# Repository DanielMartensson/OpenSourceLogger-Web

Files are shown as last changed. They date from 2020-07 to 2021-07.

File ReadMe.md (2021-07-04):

# OpenSourceLogger

This software creates a web application with Spring Boot and with this web application you can control and measure analog inputs and outputs and 
store them into a MySQL database.

# Features

* 4 Analog inputs of 12-bit
* 2 Analog inputs of 16-bit
* 3 Analog inputs of 16-bit differential
* 9 PWM control outputs
* 6 Digital inputs
* 3 Analog outputs of 12-bit
* Circuit protection from high voltage
* Spring Security Login
* MySQL database
* USB Camera view (Does not work with Raspberry Pi)
* Plotting functionality
* SMTP alarm functionality
* CSV generation of measurements
* Connect with RX and TX from Raspberry Pi pins
* Save unsaved database measurement for later if database might be slow for a moment
* Close down PWM and analog outputs when stop logging or alarm goes of

With this user view, you can control PWM, DAC, read ADC and logging digital inputs online over the web.
Set an alarm and calibration of a special sensor you want to use. Store all data inside the database. 
Then later you can bring the measurement back to a plot. Notice that you can close down the web browser while you logging.
It will continue to sample in a separate thread. 

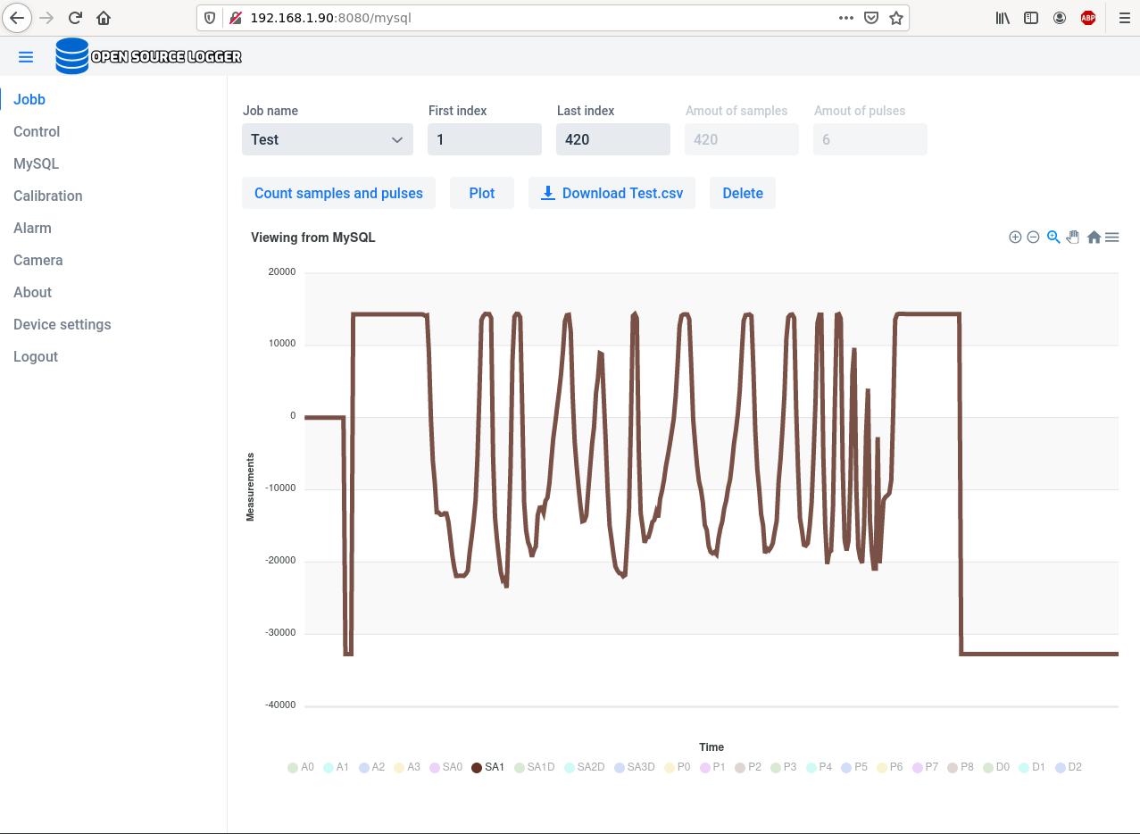
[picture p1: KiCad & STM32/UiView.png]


This is made in KiCad. I have drag all the tracks on the board by my self. No auto-routing here.

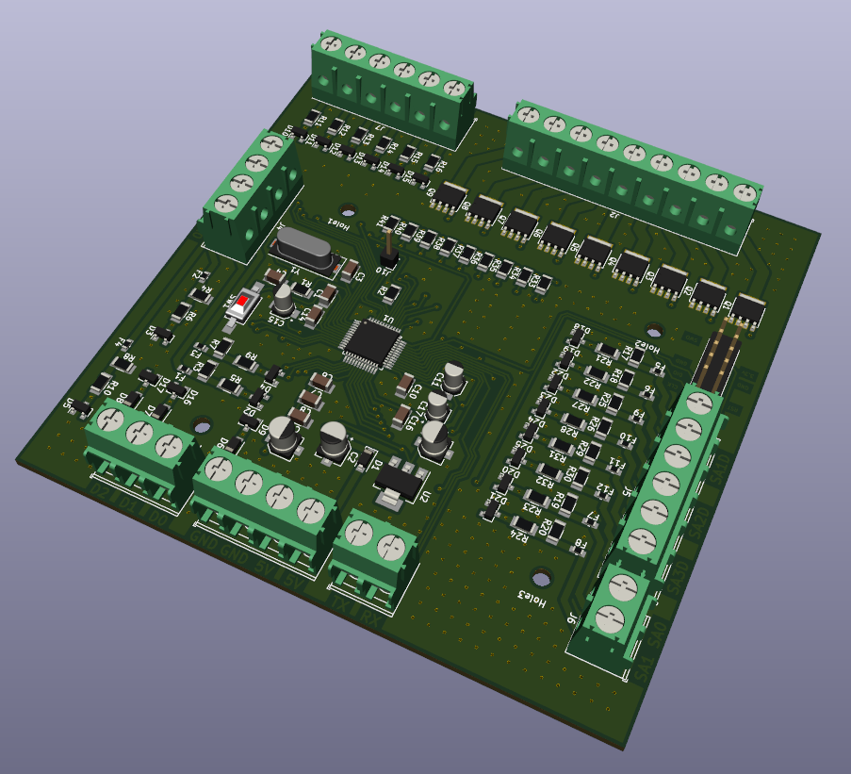
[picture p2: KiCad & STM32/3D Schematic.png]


I have solder all components by my self.

a

I have solder this microcontroller by hand. 

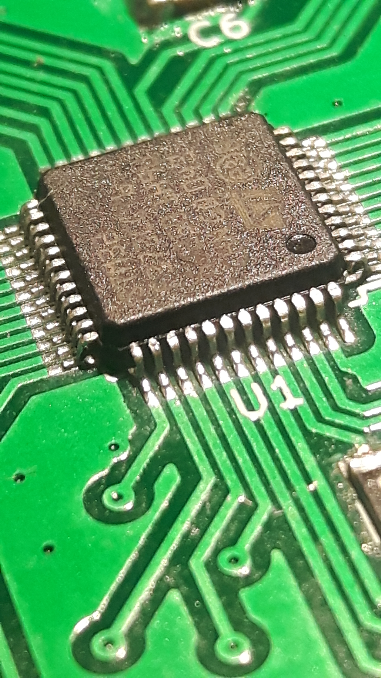
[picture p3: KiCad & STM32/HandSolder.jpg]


Applied inside a metallic box. Here I'm using Raspberry Pi to communicate with the board.
You can use a regular computer as well, as long you have a USB to serial converter, e.g `USB/UART converter FTDI FT232` where you connect `RXD -> TX` and `TXD -> RX` on the board.

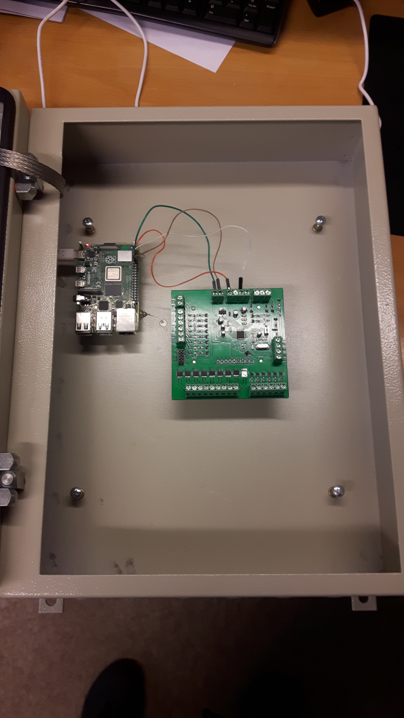
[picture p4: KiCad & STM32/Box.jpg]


# How to install - Ubuntu user

1. Install Java 11, Maven, NodeJS

Java 11
```
sudo apt-get install openjdk-11-jdk
```

Maven
```
sudo apt-get install maven
```

NodeJS
```
curl -sL https://deb.nodesource.com/setup_lts.x | sudo -E bash -
sudo apt-get install -y nodejs
```

2. Begin first to install MySQL Community Server

```
sudo apt-get install mysql-server
```

3. Then create a user e.g `myUser` with the password e.g `myPassword`

Login and enter your `sudo` password or mysql `root` password
```
sudo mysql -u root -p
```

Create user with the host `%` <-- That's important if you want to access your server from other computers.
```
CREATE USER 'myUser'@'%' IDENTIFIED BY 'myPassword';
```

Set the privileges to that user
```
GRANT ALL PRIVILEGES ON *.* TO 'myUser'@'%';
```

4. Change your MySQL server so you listening to your LAN address

Open this file
```
/etc/mysql/mysql.conf.d/mysqld.conf
```

And change this
```
bind-address            = 127.0.0.1
```

To your LAN address where the server is installed on e.g
```
bind-address            = 192.168.1.34
```

Then restart your MySQL server
```
sudo /etc/init.d/mysql restart
```

If you don't know your LAN address, you can type in this command in linux `ifconfig` in the terminal

5. Download `OpenSourceLogger`

Download the `OpenSourceLogger` and change the `application.properties` in the `/src/main/resources` folder.
Here you can set the configuration for your database IP address, user and password. Here set the address of your `Outlook` account.
The `service.MailService.from` must be the same as `configuration.MailConfiguration.username`.

```
# Database
spring.jpa.show-sql=true
spring.jpa.hibernate.ddl-auto=update
spring.jpa.properties.hibernate.dialect=org.hibernate.dialect.MySQL5Dialect
spring.datasource.url=jdbc:mysql://yourIPAddressOfTheServerWhereMySQLIsInstalled:3306/OpenSourceLogger?createDatabaseIfNotExist=true&serverTimezone=CET
spring.datasource.username=myUser
spring.datasource.password=myPassword

# Mail - Transmitter
configuration.MailConfiguration.host=smtp.office365.com
configuration.MailConfiguration.port=587
configuration.MailConfiguration.username=yourOutlookAccount@outlook.com
configuration.MailConfiguration.password=yourOutlookPassword

# Mail - Receiver
service.MailService.subject=Alarm Message Subject Title
service.MailService.from=yourOutlookAccount@outlook.com

# Login
spring.security.user.name=myUser
spring.security.user.password=myPassword
```

6. Pack this project and run

First stand inside of the folder `OpenSourceLogger` and write inside your terminal
```
mvn package -Pproduction
```

7. Starting the application

Now a JAR file is created inside the `OpenSourceLogger/target` folder. 

You can start `opensourcelogger-1.0-SNAPSHOT.jar`. First plugin your Serial UART into your USB port first, then write. 

```
sudo java -jar opensourcelogger-1.0-SNAPSHOT.jar
```

Once the application is started. You can then enter the web application e.g.

```
http://192.168.1.35:8080
```
Notice that there is no `https`, only `http`.

# Deploy onto Raspberry Pi

Notice that camera won't work on Raspberry Pi due to the latest library from [Sarox](https://github.com/sarxos/webcam-capture) cannot support Raspberry Pi 4B. But you can 
do everything else. If you want to work with this camera stuff inside `OpenSourceLogger`, please go to `CameraThread.java` class and begin to explore how to solve that problem.

Anyway! Once you got `opensourcelogger-1.0-SNAPSHOT.jar` ready, you can send it to your Raspberry Pi.

```
sudo scp opensourcelogger-1.0-SNAPSHOT.jar pi@RaspberryPiIPAddress:/The/Place/You/Want/The/Jar/File/To/Be/Saved
```

Example:

```
sudo scp opensourcelogger-1.0-SNAPSHOT.jar pi@192.168.1.35:/home/pi
```

Then open `rc.local`

```
sudo nano /etc/rc.local
```

And place these line above `exit 0`

```
cd /The/Path/To/Where/The/Jar/File/Is/Placed
sudo java -jar opensourcelogger-1.0-SNAPSHOT.jar &
```
Or if you want to specify the Java Heap Space for e.g `1024` Megabyte. Can be good if you want to download `.csv` data from the database.
```
cd /The/Path/To/Where/The/Jar/File/Is/Placed
sudo java -Xmx1024m -jar opensourcelogger-1.0-SNAPSHOT.jar &
```

Important with `&`, else Raspberry Pi is going to get stuck there with the `Spring Boot` terminal at the startup.

Then you need to enable `Serial` in Raspberry Pi.
```
sudo raspi-config
```
Then enable `Serial`. It's at the same page where you enable `SSH`, `VNC`, `I2C` etc. 
Once you found `Serial` option, answer `NO` to the question about login shell.
Then answer `YES` to the question about serial hardware port.
Then when you exit the `raspi-config`, it will ask you if you want to reboot, press `YES`

Now your `OpenSourceLogger` will starts automatically. Select the port `ttyS0` in `Device settings` at `OpenSourceLogger` and save the configuration
inside the database. `ttyS0` is the `RX` and `TX` pins of the Raspberry Pi. Done!

# Build an own board

Download `DAC ADC PWM IO - Board Schematic` and `DAC ADC PWM IO - STM32 Code` folder.
Inside the `DAC ADC PWM IO - Board Schematic` folder, there is a `.csv` Bill Of Materials list with article numbers from Mouser Electronics. 
I have been using `KiCad` to create these files and I used `https://jlcpcb.com` to give them the `gerber` files from the `DAC ADC PWM IO - Board Schematic` folder.

To program the board, use a `ST-LINK-V2` programmer to program the board with `STM32CubeIDE 1.5.0`.

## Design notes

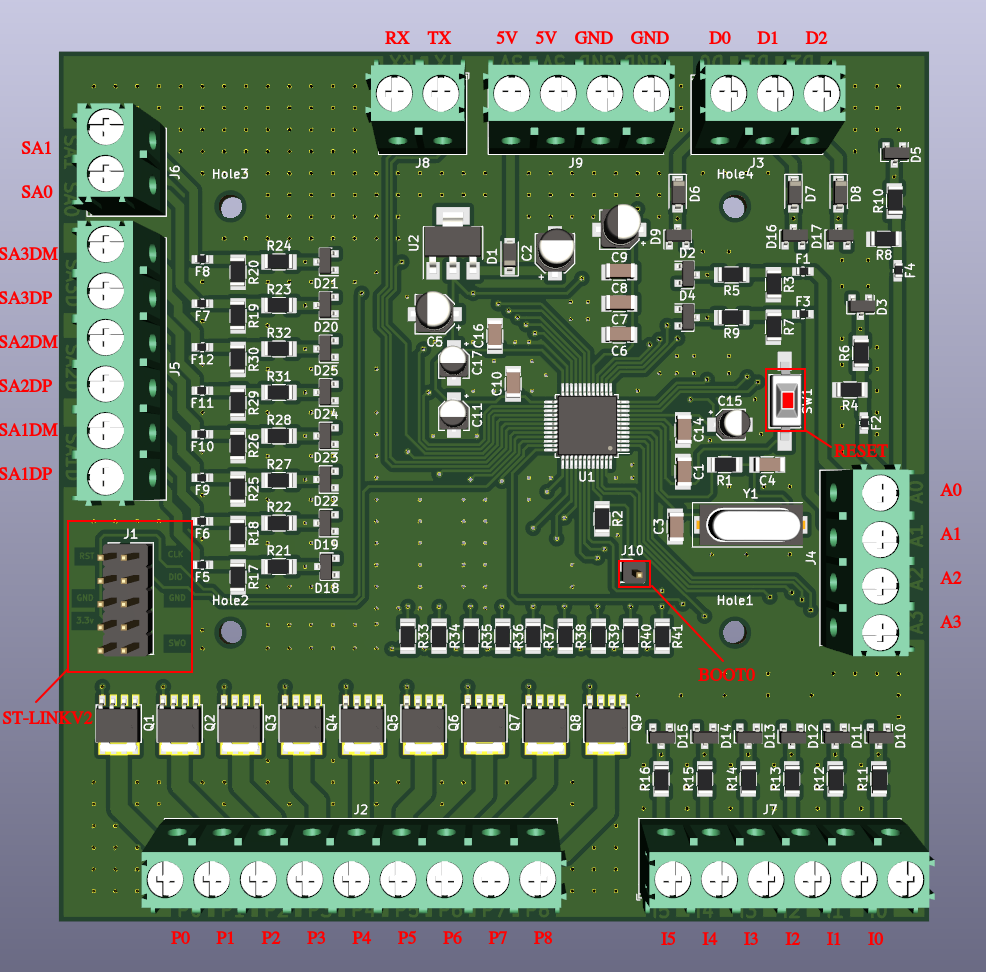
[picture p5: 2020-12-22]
src/main/resources/META-INF/resources/img/board.png

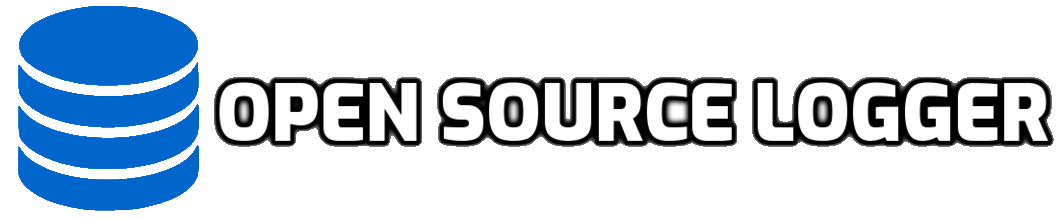
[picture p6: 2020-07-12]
src/main/resources/META-INF/resources/img/barPicture.png

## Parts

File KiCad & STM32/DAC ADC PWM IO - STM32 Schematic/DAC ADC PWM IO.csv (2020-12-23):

Source: | /home/dell/Dokument/KiCad/DAC ADC PWM IO/DAC ADC PWM IO.sch
Date: | tor 3 dec 2020 13:34:01
Tool: | Eeschema 5.1.8-db9833491~88~ubuntu18.04.1
Generator: | /usr/share/kicad/plugins/bom_csv_grouped_by_value.py
Component Count: | 116
Individual Components:
Item | Qty | Reference(s) | Value | LibPart | Footprint | Datasheet
 |  | C1 | 100nF | Device:C | Capacitor_SMD:C_1206_3216Metric | 710-885012208058
 |  | C2 | 10uF | Device:CP | Capacitor_SMD:CP_Elec_4x5.3 | 140-VE100M1CTR0405
 |  | C3 | 16pF | Device:C | Capacitor_SMD:C_1206_3216Metric | 80-C1206C160K3HACTU
 |  | C4 | 16pF | Device:C | Capacitor_SMD:C_1206_3216Metric | 80-C1206C160K3HACTU
 |  | C5 | 10uF | Device:CP | Capacitor_SMD:CP_Elec_4x5.3 | 140-VE100M1CTR0405
 |  | C6 | 100nF | Device:C | Capacitor_SMD:C_1206_3216Metric | 710-885012208058
 |  | C7 | 100nF | Device:C | Capacitor_SMD:C_1206_3216Metric | 710-885012208058
 |  | C8 | 100nF | Device:C | Capacitor_SMD:C_1206_3216Metric | 710-885012208058
 |  | C9 | 4.7uF | Device:CP | Capacitor_SMD:CP_Elec_4x5.4 | 647-UWJ1E4R7MCL1
 |  | C10 | 10nF | Device:C | Capacitor_SMD:C_1206_3216Metric | 710-885012208112
 |  | C11 | 1uF | Device:CP | Capacitor_SMD:CP_Elec_3x5.4 | 647-UWX1H010MCL2
 |  | C14 | 10nF | Device:C | Capacitor_SMD:C_1206_3216Metric | 710-885012208112
 |  | C15 | 1uF | Device:CP | Capacitor_SMD:CP_Elec_3x5.4 | 647-UWX1H010MCL2
 |  | C16 | 10nF | Device:C | Capacitor_SMD:C_1206_3216Metric | 710-885012208112
 |  | C17 | 1uF | Device:CP | Capacitor_SMD:CP_Elec_3x5.4 | 647-UWX1H010MCL2
 |  | D1 | MBR130T1G | Device:D_Schottky | Diode_SMD:D_SOD-123 | 863-MBR130T1G
 |  | D2 | BZX84C3V6LT1G | Diode:BZX84Cxx | Diode_SMD:D_SOT-23_ANK | 863-BZX84C3V6LT1G
 |  | D3 | BZX84C3V6LT1G | Diode:BZX84Cxx | Diode_SMD:D_SOT-23_ANK | 863-BZX84C3V6LT1G
 |  | D4 | BZX84C3V6LT1G | Diode:BZX84Cxx | Diode_SMD:D_SOT-23_ANK | 863-BZX84C3V6LT1G
 |  | D5 | BZX84C3V6LT1G | Diode:BZX84Cxx | Diode_SMD:D_SOT-23_ANK | 863-BZX84C3V6LT1G
 |  | D6 | BAT54T1G | Device:D_Schottky | Diode_SMD:D_SOD-123 | 863-BAT54T1G
 |  | D7 | BAT54T1G | Device:D_Schottky | Diode_SMD:D_SOD-123 | 863-BAT54T1G
 |  | D8 | BAT54T1G | Device:D_Schottky | Diode_SMD:D_SOD-123 | 863-BAT54T1G
 |  | D9 | BZX84C3V6LT1G | Diode:BZX84Cxx | Diode_SMD:D_SOT-23_ANK | 863-BZX84C3V6LT1G
 |  | D10 | BZX84C3V6LT1G | Diode:BZX84Cxx | Diode_SMD:D_SOT-23_ANK | 863-BZX84C3V6LT1G
 |  | D11 | BZX84C3V6LT1G | Diode:BZX84Cxx | Diode_SMD:D_SOT-23_ANK | 863-BZX84C3V6LT1G
 |  | D12 | BZX84C3V6LT1G | Diode:BZX84Cxx | Diode_SMD:D_SOT-23_ANK | 863-BZX84C3V6LT1G
 |  | D13 | BZX84C3V6LT1G | Diode:BZX84Cxx | Diode_SMD:D_SOT-23_ANK | 863-BZX84C3V6LT1G
 |  | D14 | BZX84C3V6LT1G | Diode:BZX84Cxx | Diode_SMD:D_SOT-23_ANK | 863-BZX84C3V6LT1G
 |  | D15 | BZX84C3V6LT1G | Diode:BZX84Cxx | Diode_SMD:D_SOT-23_ANK | 863-BZX84C3V6LT1G
 |  | D16 | BZX84C3V6LT1G | Diode:BZX84Cxx | Diode_SMD:D_SOT-23_ANK | 863-BZX84C3V6LT1G
 |  | D17 | BZX84C3V6LT1G | Diode:BZX84Cxx | Diode_SMD:D_SOT-23_ANK | 863-BZX84C3V6LT1G
 |  | D18 | BZX84C3V6LT1G | Diode:BZX84Cxx | Diode_SMD:D_SOT-23_ANK | 863-BZX84C3V6LT1G
 |  | D19 | BZX84C3V6LT1G | Diode:BZX84Cxx | Diode_SMD:D_SOT-23_ANK | 863-BZX84C3V6LT1G
 |  | D20 | BZX84C3V6LT1G | Diode:BZX84Cxx | Diode_SMD:D_SOT-23_ANK | 863-BZX84C3V6LT1G
 |  | D21 | BZX84C3V6LT1G | Diode:BZX84Cxx | Diode_SMD:D_SOT-23_ANK | 863-BZX84C3V6LT1G
 |  | D22 | BZX84C3V6LT1G | Diode:BZX84Cxx | Diode_SMD:D_SOT-23_ANK | 863-BZX84C3V6LT1G
 |  | D23 | BZX84C3V6LT1G | Diode:BZX84Cxx | Diode_SMD:D_SOT-23_ANK | 863-BZX84C3V6LT1G
 |  | D24 | BZX84C3V6LT1G | Diode:BZX84Cxx | Diode_SMD:D_SOT-23_ANK | 863-BZX84C3V6LT1G
 |  | D25 | BZX84C3V6LT1G | Diode:BZX84Cxx | Diode_SMD:D_SOT-23_ANK | 863-BZX84C3V6LT1G
 |  | F1 | Polyfuse | Device:Polyfuse | Fuse:Fuse_0603_1608Metric | 530-0ZCM0002FF2G
 |  | F2 | Polyfuse | Device:Polyfuse | Fuse:Fuse_0603_1608Metric | 530-0ZCM0002FF2G
 |  | F3 | Polyfuse | Device:Polyfuse | Fuse:Fuse_0603_1608Metric | 530-0ZCM0002FF2G
 |  | F4 | Polyfuse | Device:Polyfuse | Fuse:Fuse_0603_1608Metric | 530-0ZCM0002FF2G
 |  | F5 | Polyfuse | Device:Polyfuse | Fuse:Fuse_0603_1608Metric | 530-0ZCM0002FF2G
 |  | F6 | Polyfuse | Device:Polyfuse | Fuse:Fuse_0603_1608Metric | 530-0ZCM0002FF2G
 |  | F7 | Polyfuse | Device:Polyfuse | Fuse:Fuse_0603_1608Metric | 530-0ZCM0002FF2G
 |  | F8 | Polyfuse | Device:Polyfuse | Fuse:Fuse_0603_1608Metric | 530-0ZCM0002FF2G
 |  | F9 | Polyfuse | Device:Polyfuse | Fuse:Fuse_0603_1608Metric | 530-0ZCM0002FF2G
 |  | F10 | Polyfuse | Device:Polyfuse | Fuse:Fuse_0603_1608Metric | 530-0ZCM0002FF2G
 |  | F11 | Polyfuse | Device:Polyfuse | Fuse:Fuse_0603_1608Metric | 530-0ZCM0002FF2G
 |  | F12 | Polyfuse | Device:Polyfuse | Fuse:Fuse_0603_1608Metric | 530-0ZCM0002FF2G
 |  | J1 | Debugger | Connector_Generic:Conn_02x05_Odd_Even | Connector_PinHeader_2.54mm:PinHeader_2x05_P2.54mm_Vertical | 710-61201021621
 |  | J2 | PWM | Connector:Screw_Terminal_01x09 | TerminalBlock_Phoenix:TerminalBlock_Phoenix_PT-1,5-9-5.0-H_1x09_P5.00mm_Horizontal | 651-1935239
 |  | J3 | DAC | Connector:Screw_Terminal_01x03 | TerminalBlock_Phoenix:TerminalBlock_Phoenix_PT-1,5-3-5.0-H_1x03_P5.00mm_Horizontal | 651-1935174
 |  | J4 | 4-20mA 12-bit | Connector:Screw_Terminal_01x04 | TerminalBlock_Phoenix:TerminalBlock_Phoenix_PT-1,5-4-5.0-H_1x04_P5.00mm_Horizontal | 651-1935187
 |  | J5 | 4-20mA 16-bit Differential | Connector:Screw_Terminal_01x06 | TerminalBlock_Phoenix:TerminalBlock_Phoenix_PT-1,5-6-5.0-H_1x06_P5.00mm_Horizontal | 651-1935200
 |  | J6 | 4-20mA 16-bit | Connector:Screw_Terminal_01x02 | TerminalBlock_Phoenix:TerminalBlock_Phoenix_PT-1,5-2-5.0-H_1x02_P5.00mm_Horizontal | 651-1935161
 |  | J7 | Input | Connector:Screw_Terminal_01x06 | TerminalBlock_Phoenix:TerminalBlock_Phoenix_PT-1,5-6-5.0-H_1x06_P5.00mm_Horizontal | 651-1935200
 |  | J8 | UART | Connector:Screw_Terminal_01x02 | TerminalBlock_Phoenix:TerminalBlock_Phoenix_PT-1,5-2-5.0-H_1x02_P5.00mm_Horizontal | 651-1935161
 |  | J9 | PWR | Connector:Screw_Terminal_01x04 | TerminalBlock_Phoenix:TerminalBlock_Phoenix_PT-1,5-4-5.0-H_1x04_P5.00mm_Horizontal | 651-1935187
 |  | J10 | Conn_01x01_MountingPin | Connector_Generic_MountingPin:Conn_01x01_MountingPin | Connector_PinHeader_2.54mm:PinHeader_1x01_P2.54mm_Vertical | ~
 |  | Q1 | BUK9Y43-60E,115 | Transistor_FET:BUK9M23-80EX | Package_TO_SOT_SMD:LFPAK56 | 771-BUK9Y43-60E115
 |  | Q2 | BUK9Y43-60E,115 | Transistor_FET:BUK9M23-80EX | Package_TO_SOT_SMD:LFPAK56 | 771-BUK9Y43-60E115
 |  | Q3 | BUK9Y43-60E,115 | Transistor_FET:BUK9M23-80EX | Package_TO_SOT_SMD:LFPAK56 | 771-BUK9Y43-60E115
 |  | Q4 | BUK9Y43-60E,115 | Transistor_FET:BUK9M23-80EX | Package_TO_SOT_SMD:LFPAK56 | 771-BUK9Y43-60E115
 |  | Q5 | BUK9Y43-60E,115 | Transistor_FET:BUK9M23-80EX | Package_TO_SOT_SMD:LFPAK56 | 771-BUK9Y43-60E115
 |  | Q6 | BUK9Y43-60E,115 | Transistor_FET:BUK9M23-80EX | Package_TO_SOT_SMD:LFPAK56 | 771-BUK9Y43-60E115
 |  | Q7 | BUK9Y43-60E,115 | Transistor_FET:BUK9M23-80EX | Package_TO_SOT_SMD:LFPAK56 | 771-BUK9Y43-60E115
 |  | Q8 | BUK9Y43-60E,115 | Transistor_FET:BUK9M23-80EX | Package_TO_SOT_SMD:LFPAK56 | 771-BUK9Y43-60E115
 |  | Q9 | BUK9Y43-60E,115 | Transistor_FET:BUK9M23-80EX | Package_TO_SOT_SMD:LFPAK56 | 771-BUK9Y43-60E115
 |  | R1 | 620 | Device:R | Resistor_SMD:R_1206_3216Metric | 652-CR1206FX-6200ELF
 |  | R2 | 10k | Device:R | Resistor_SMD:R_1206_3216Metric | 71-CRCW120610K0FKEAC
 |  | R3 | 150 | Device:R | Resistor_SMD:R_1206_3216Metric | 660-SG73P2BTTD151G
 |  | R4 | 150 | Device:R | Resistor_SMD:R_1206_3216Metric | 660-SG73P2BTTD151G
 |  | R5 | 2k | Device:R | Resistor_SMD:R_1206_3216Metric | 71-CRCW12062K00FKEAC
 |  | R6 | 2k | Device:R | Resistor_SMD:R_1206_3216Metric | 71-CRCW12062K00FKEAC
 |  | R7 | 150 | Device:R | Resistor_SMD:R_1206_3216Metric | 660-SG73P2BTTD151G
 |  | R8 | 150 | Device:R | Resistor_SMD:R_1206_3216Metric | 660-SG73P2BTTD151G
 |  | R9 | 2k | Device:R | Resistor_SMD:R_1206_3216Metric | 71-CRCW12062K00FKEAC
 |  | R10 | 2k | Device:R | Resistor_SMD:R_1206_3216Metric | 71-CRCW12062K00FKEAC
 |  | R11 | 10k | Device:R | Resistor_SMD:R_1206_3216Metric | ~
 |  | R12 | 10k | Device:R | Resistor_SMD:R_1206_3216Metric | ~
 |  | R13 | 10k | Device:R | Resistor_SMD:R_1206_3216Metric | ~
 |  | R14 | 10k | Device:R | Resistor_SMD:R_1206_3216Metric | ~
 |  | R15 | 10k | Device:R | Resistor_SMD:R_1206_3216Metric | ~
 |  | R16 | 10k | Device:R | Resistor_SMD:R_1206_3216Metric | ~
 |  | R17 | 150 | Device:R | Resistor_SMD:R_1206_3216Metric | 660-SG73P2BTTD151G
 |  | R18 | 150 | Device:R | Resistor_SMD:R_1206_3216Metric | 660-SG73P2BTTD151G
 |  | R19 | 150 | Device:R | Resistor_SMD:R_1206_3216Metric | 660-SG73P2BTTD151G
 |  | R20 | 150 | Device:R | Resistor_SMD:R_1206_3216Metric | 660-SG73P2BTTD151G
 |  | R21 | 2k | Device:R | Resistor_SMD:R_1206_3216Metric | 71-CRCW12062K00FKEAC
 |  | R22 | 2k | Device:R | Resistor_SMD:R_1206_3216Metric | 71-CRCW12062K00FKEAC
 |  | R23 | 2k | Device:R | Resistor_SMD:R_1206_3216Metric | 71-CRCW12062K00FKEAC
 |  | R24 | 2k | Device:R | Resistor_SMD:R_1206_3216Metric | 71-CRCW12062K00FKEAC
 |  | R25 | 150 | Device:R | Resistor_SMD:R_1206_3216Metric | 660-SG73P2BTTD151G
 |  | R26 | 150 | Device:R | Resistor_SMD:R_1206_3216Metric | 660-SG73P2BTTD151G
 |  | R27 | 2k | Device:R | Resistor_SMD:R_1206_3216Metric | 71-CRCW12062K00FKEAC
 |  | R28 | 2k | Device:R | Resistor_SMD:R_1206_3216Metric | 71-CRCW12062K00FKEAC
 |  | R29 | 150 | Device:R | Resistor_SMD:R_1206_3216Metric | 660-SG73P2BTTD151G
 |  | R30 | 150 | Device:R | Resistor_SMD:R_1206_3216Metric | 660-SG73P2BTTD151G
 |  | R31 | 2k | Device:R | Resistor_SMD:R_1206_3216Metric | 71-CRCW12062K00FKEAC
 |  | R32 | 2k | Device:R | Resistor_SMD:R_1206_3216Metric | 71-CRCW12062K00FKEAC
 |  | R33 | 1k | Device:R | Resistor_SMD:R_1206_3216Metric | 71-CRCW12061K00FKEBC
 |  | R34 | 1k | Device:R | Resistor_SMD:R_1206_3216Metric | 71-CRCW12061K00FKEBC
 |  | R35 | 1k | Device:R | Resistor_SMD:R_1206_3216Metric | 71-CRCW12061K00FKEBC
 |  | R36 | 1k | Device:R | Resistor_SMD:R_1206_3216Metric | 71-CRCW12061K00FKEBC
 |  | R37 | 1k | Device:R | Resistor_SMD:R_1206_3216Metric | 71-CRCW12061K00FKEBC
 |  | R38 | 1k | Device:R | Resistor_SMD:R_1206_3216Metric | 71-CRCW12061K00FKEBC
 |  | R39 | 1k | Device:R | Resistor_SMD:R_1206_3216Metric | 71-CRCW12061K00FKEBC
 |  | R40 | 1k | Device:R | Resistor_SMD:R_1206_3216Metric | 71-CRCW12061K00FKEBC
 |  | R41 | 1k | Device:R | Resistor_SMD:R_1206_3216Metric | 71-CRCW12061K00FKEBC
 |  | SW1 | SW_Push | Switch:SW_Push | Button_Switch_SMD:SW_SPST_FSMSM | 506-FSMSM
 |  | U1 | STM32F373C8Tx | MCU_ST_STM32F3:STM32F373C8Tx | Package_QFP:LQFP-48_7x7mm_P0.5mm | 511-STM32F373C8T6
 |  | U2 | LM1117-3.3 | Regulator_Linear:LM1117-3.3 | Package_TO_SOT_SMD:SOT-223 | 926-LM1117MP-3.3NOPB
 |  | Y1 | 16Mhz, 18pF | Device:Crystal | Crystal:Crystal_SMD_HC49-SD | 449-LFXTAL034655BULK
Collated Components:
Item | Qty | Reference(s) | Value | LibPart | Footprint | Datasheet | Total qty | Köpte istället | Markerat
1 | 4 | C1, C6, C7, C8 | 100nF | Device:C | Capacitor_SMD:C_1206_3216Metric | 710-885012208058 | 8
2 | 2 | C2, C5 | 10uF | Device:CP | Capacitor_SMD:CP_Elec_4x5.3 | 140-VE100M1CTR0405 | 4 | 555-RVS-10V100MU-R
3 | 2 | C3, C4 | 16pF | Device:C | Capacitor_SMD:C_1206_3216Metric | 80-C1206C160K3HACTU | 4
4 | 1 | C9 | 4.7uF | Device:CP | Capacitor_SMD:CP_Elec_4x5.4 | 647-UWJ1E4R7MCL1 | 2 |  | OK
5 | 3 | C10, C14, C16 | 10nF | Device:C | Capacitor_SMD:C_1206_3216Metric | 710-885012208112 | 6
6 | 3 | C11, C15, C17 | 1uF | Device:CP | Capacitor_SMD:CP_Elec_3x5.4 | 647-UWX1H010MCL2 | 6
7 | 1 | D1 | MBR130T1G | Device:D_Schottky | Diode_SMD:D_SOD-123 | 863-MBR130T1G | 2
8 | 21 | D2, D3, D4, D5, D9, D10, D11, D12, D13, D14, D15, D16, D17, D18, D19, D20, D21, D22, D23, D24, D25 | BZX84C3V6LT1G | Diode:BZX84Cxx | Diode_SMD:D_SOT-23_ANK | 863-BZX84C3V6LT1G | 42
9 | 3 | D6, D7, D8 | BAT54T1G | Device:D_Schottky | Diode_SMD:D_SOD-123 | 863-BAT54T1G | 6
10 | 12 | F1, F2, F3, F4, F5, F6, F7, F8, F9, F10, F11, F12 | Polyfuse | Device:Polyfuse | Fuse:Fuse_0603_1608Metric | 530-0ZCM0002FF2G | 24
11 | 1 | J1 | Debugger | Connector_Generic:Conn_02x05_Odd_Even | Connector_PinHeader_2.54mm:PinHeader_2x05_P2.54mm_Vertical | 710-61201021621 | 2 | Köpte inte in – Behövs ej
12 | 1 | J2 | PWM | Connector:Screw_Terminal_01x09 | TerminalBlock_Phoenix:TerminalBlock_Phoenix_PT-1,5-9-5.0-H_1x09_P5.00mm_Horizontal | 651-1935239 | 2
13 | 1 | J3 | DAC | Connector:Screw_Terminal_01x03 | TerminalBlock_Phoenix:TerminalBlock_Phoenix_PT-1,5-3-5.0-H_1x03_P5.00mm_Horizontal | 651-1935174 | 2
14 | 1 | J4 | 4-20mA 12-bit | Connector:Screw_Terminal_01x04 | TerminalBlock_Phoenix:TerminalBlock_Phoenix_PT-1,5-4-5.0-H_1x04_P5.00mm_Horizontal | 651-1935187 | 2
15 | 1 | J5 | 4-20mA 16-bit Differential | Connector:Screw_Terminal_01x06 | TerminalBlock_Phoenix:TerminalBlock_Phoenix_PT-1,5-6-5.0-H_1x06_P5.00mm_Horizontal | 651-1935200 | 2
16 | 1 | J6 | 4-20mA 16-bit | Connector:Screw_Terminal_01x02 | TerminalBlock_Phoenix:TerminalBlock_Phoenix_PT-1,5-2-5.0-H_1x02_P5.00mm_Horizontal | 651-1935161 | 2
17 | 1 | J7 | Input | Connector:Screw_Terminal_01x06 | TerminalBlock_Phoenix:TerminalBlock_Phoenix_PT-1,5-6-5.0-H_1x06_P5.00mm_Horizontal | 651-1935200 | 2
18 | 1 | J8 | UART | Connector:Screw_Terminal_01x02 | TerminalBlock_Phoenix:TerminalBlock_Phoenix_PT-1,5-2-5.0-H_1x02_P5.00mm_Horizontal | 651-1935161 | 2
19 | 1 | J9 | PWR | Connector:Screw_Terminal_01x04 | TerminalBlock_Phoenix:TerminalBlock_Phoenix_PT-1,5-4-5.0-H_1x04_P5.00mm_Horizontal | 651-1935187 | 2
20 | 1 | J10 | Conn_01x01_MountingPin | Connector_Generic_MountingPin:Conn_01x01_MountingPin | Connector_PinHeader_2.54mm:PinHeader_1x01_P2.54mm_Vertical | ~ | 2
21 | 9 | Q1, Q2, Q3, Q4, Q5, Q6, Q7, Q8, Q9 | BUK9Y43-60E,115 | Transistor_FET:BUK9M23-80EX | Package_TO_SOT_SMD:LFPAK56 | 771-BUK9Y43-60E115 | 18 |  | OK
22 | 1 | R1 | 620 | Device:R | Resistor_SMD:R_1206_3216Metric | 652-CR1206FX-6200ELF | 2
23 | 7 | R2, R11, R12, R13, R14, R15, R16 | 10k | Device:R | Resistor_SMD:R_1206_3216Metric | 71-CRCW120610K0FKEAC | 14
24 | 12 | R3, R4, R7, R8, R17, R18, R19, R20, R25, R26, R29, R30 | 150 | Device:R | Resistor_SMD:R_1206_3216Metric | 660-SG73P2BTTD151G | 24
25 | 12 | R5, R6, R9, R10, R21, R22, R23, R24, R27, R28, R31, R32 | 2k | Device:R | Resistor_SMD:R_1206_3216Metric | 71-CRCW12062K00FKEAC | 24
26 | 9 | R33, R34, R35, R36, R37, R38, R39, R40, R41 | 1k | Device:R | Resistor_SMD:R_1206_3216Metric | 71-CRCW12061K00FKEBC | 18
27 | 1 | SW1 | SW_Push | Switch:SW_Push | Button_Switch_SMD:SW_SPST_FSMSM | 506-FSMSM | 2
28 | 1 | U1 | STM32F373C8Tx | MCU_ST_STM32F3:STM32F373C8Tx | Package_QFP:LQFP-48_7x7mm_P0.5mm | 511-STM32F373CCT6 | 2
29 | 1 | U2 | LM1117-3.3 | Regulator_Linear:LM1117-3.3 | Package_TO_SOT_SMD:SOT-223 | 926-LM1117MP-3.3NOPB | 2
30 | 1 | Y1 | 16Mhz, 18pF | Device:Crystal | Crystal:Crystal_SMD_HC49-SD | 449-LFXTAL034655BULK | 2

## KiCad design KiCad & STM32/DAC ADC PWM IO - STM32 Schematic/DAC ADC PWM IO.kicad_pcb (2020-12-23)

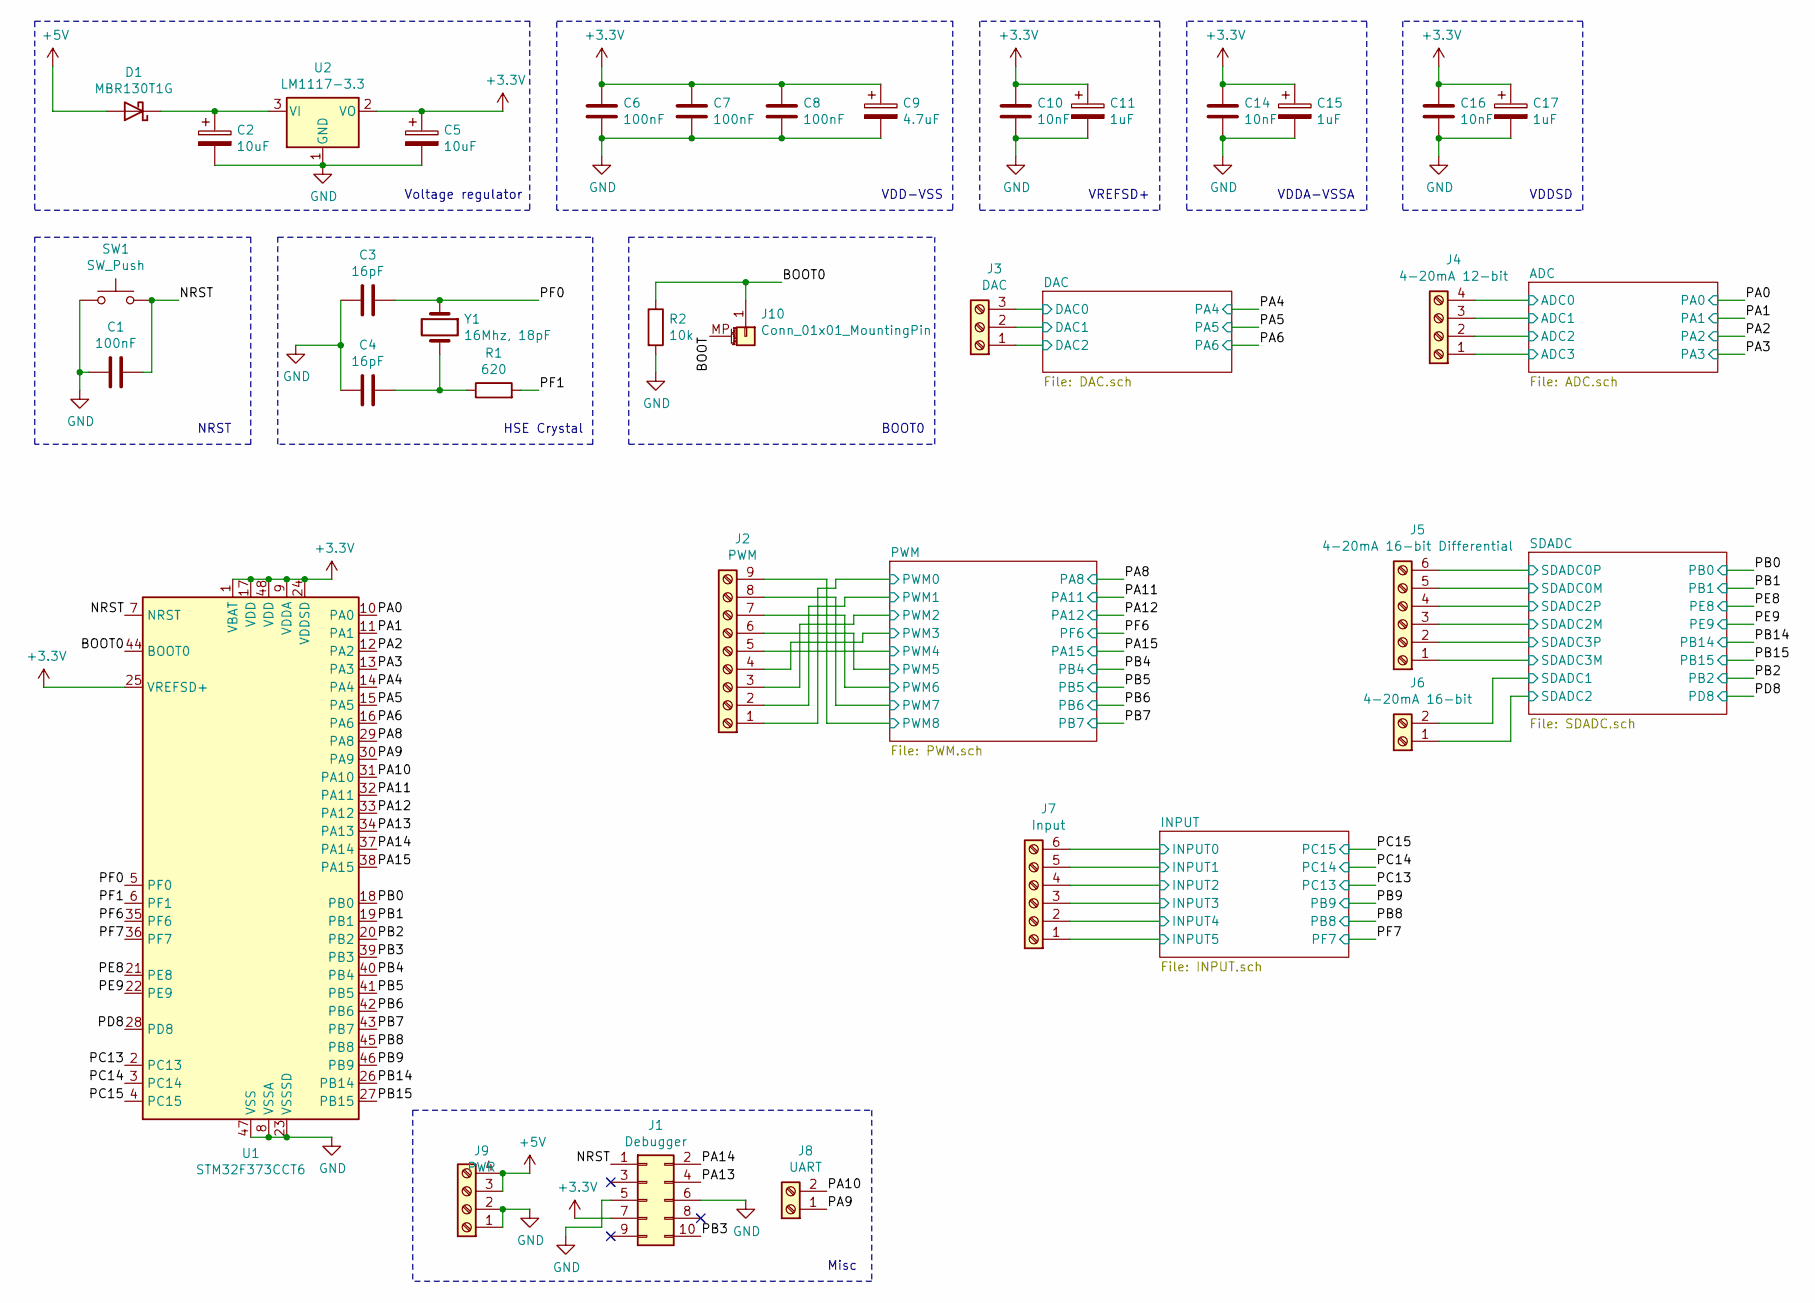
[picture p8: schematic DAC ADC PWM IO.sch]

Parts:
C1, C6, C7, C8: 100nF; C_1206_3216Metric
C2, C5: 10uF; CP_Elec_4x5.3
C3, C4: 16pF; C_1206_3216Metric
C9: 4.7uF; CP_Elec_4x5.4
C10, C14, C16: 10nF; C_1206_3216Metric
C11, C15, C17: 1uF; CP_Elec_3x5.4
D1: MBR130T1G; D_SOD-123
J1: Debugger; PinHeader_2x05_P2.54mm_Vertical
J2: PWM; TerminalBlock_Phoenix_PT-1,5-9-5.0-H_1x09_P5.00mm_Horizontal
J3: DAC; TerminalBlock_Phoenix_PT-1,5-3-5.0-H_1x03_P5.00mm_Horizontal
J4: 4-20mA 12-bit; TerminalBlock_Phoenix_PT-1,5-4-5.0-H_1x04_P5.00mm_Horizontal
J5: 4-20mA 16-bit Differential; TerminalBlock_Phoenix_PT-1,5-6-5.0-H_1x06_P5.00mm_Horizontal
J6: 4-20mA 16-bit; TerminalBlock_Phoenix_PT-1,5-2-5.0-H_1x02_P5.00mm_Horizontal
J7: Input; TerminalBlock_Phoenix_PT-1,5-6-5.0-H_1x06_P5.00mm_Horizontal
J8: UART; TerminalBlock_Phoenix_PT-1,5-2-5.0-H_1x02_P5.00mm_Horizontal
J9: PWR; TerminalBlock_Phoenix_PT-1,5-4-5.0-H_1x04_P5.00mm_Horizontal
J10: Conn_01x01_MountingPin; PinHeader_1x01_P2.54mm_Vertical
R1: 620; R_1206_3216Metric
R2: 10k; R_1206_3216Metric
SW1: SW_Push; SW_SPST_FSMSM
U1: STM32F373CCT6; LQFP-48_7x7mm_P0.5mm
U2: LM1117-3.3; SOT-223
Y1: 16Mhz, 18pF; Crystal_SMD_HC49-SD

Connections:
+3V3: C5.1, C6.1, C7.1, C8.1, C9.1, C10.1, C11.1, C14.1, C15.1, C16.1, C17.1, J1.7, U1.1 (VBAT), U1.9 (VDDA), U1.17 (VDD), U1.24 (VDDSD), U1.25 (VREFSD+), U1.48 (VDD), U2.2 (VO)
+5V: D1.2 (A), J9.3, J9.4
/ADC/ADC0: J4.4; also elsewhere on the board
/ADC/ADC1: J4.3; also elsewhere on the board
/ADC/ADC2: J4.2; also elsewhere on the board
/ADC/ADC3: J4.1; also elsewhere on the board
/BOOT0: J10.1, R2.1, U1.44 (BOOT0)
/DAC/DAC0: J3.3; also elsewhere on the board
/DAC/DAC1: J3.2; also elsewhere on the board
/DAC/DAC2: J3.1; also elsewhere on the board
/INPUT/INPUT0: J7.6; also elsewhere on the board
/INPUT/INPUT1: J7.5; also elsewhere on the board
/INPUT/INPUT2: J7.4; also elsewhere on the board
/INPUT/INPUT3: J7.3; also elsewhere on the board
/INPUT/INPUT4: J7.2; also elsewhere on the board
/INPUT/INPUT5: J7.1; also elsewhere on the board
/NRST: C1.2, J1.1, SW1.2, U1.7 (NRST)
/PA0: U1.10 (PA0); also elsewhere on the board
/PA1: U1.11 (PA1); also elsewhere on the board
/PA2: U1.12 (PA2); also elsewhere on the board
/PA3: U1.13 (PA3); also elsewhere on the board
/PA4: U1.14 (PA4); also elsewhere on the board
/PA5: U1.15 (PA5); also elsewhere on the board
/PA6: U1.16 (PA6); also elsewhere on the board
/PA8: U1.29 (PA8); also elsewhere on the board
/PA9: J8.1, U1.30 (PA9)
/PA10: J8.2, U1.31 (PA10)
/PA11: U1.32 (PA11); also elsewhere on the board
/PA12: U1.33 (PA12); also elsewhere on the board
/PA13: J1.4, U1.34 (PA13)
/PA14: J1.2, U1.37 (PA14)
/PA15: U1.38 (PA15); also elsewhere on the board
/PB0: U1.18 (PB0); also elsewhere on the board
/PB1: U1.19 (PB1); also elsewhere on the board
/PB2: U1.20 (PB2); also elsewhere on the board
/PB3: J1.10, U1.39 (PB3)
/PB4: U1.40 (PB4); also elsewhere on the board
/PB5: U1.41 (PB5); also elsewhere on the board
/PB6: U1.42 (PB6); also elsewhere on the board
/PB7: U1.43 (PB7); also elsewhere on the board
/PB8: U1.45 (PB8); also elsewhere on the board
/PB9: U1.46 (PB9); also elsewhere on the board
/PB14: U1.26 (PB14); also elsewhere on the board
/PB15: U1.27 (PB15); also elsewhere on the board
/PC13: U1.2 (PC13); also elsewhere on the board
/PC14: U1.3 (PC14); also elsewhere on the board
/PC15: U1.4 (PC15); also elsewhere on the board
/PD8: U1.28 (PD8); also elsewhere on the board
/PE8: U1.21 (PE8); also elsewhere on the board
/PE9: U1.22 (PE9); also elsewhere on the board
/PF0: C3.2, U1.5 (PF0), Y1.1
/PF1: R1.2, U1.6 (PF1)
/PF6: U1.35 (PF6); also elsewhere on the board
/PF7: U1.36 (PF7); also elsewhere on the board
/PWM/PWM0: J2.1; also elsewhere on the board
/PWM/PWM1: J2.2; also elsewhere on the board
/PWM/PWM2: J2.3; also elsewhere on the board
/PWM/PWM3: J2.4; also elsewhere on the board
/PWM/PWM4: J2.5; also elsewhere on the board
/PWM/PWM5: J2.6; also elsewhere on the board
/PWM/PWM6: J2.7; also elsewhere on the board
/PWM/PWM7: J2.8; also elsewhere on the board
/PWM/PWM8: J2.9; also elsewhere on the board
/SDADC/SDADC0M: J5.5; also elsewhere on the board
/SDADC/SDADC0P: J5.6; also elsewhere on the board
/SDADC/SDADC1: J6.2; also elsewhere on the board
/SDADC/SDADC2: J6.1; also elsewhere on the board
/SDADC/SDADC2M: J5.3; also elsewhere on the board
/SDADC/SDADC2P: J5.4; also elsewhere on the board
/SDADC/SDADC3M: J5.1; also elsewhere on the board
/SDADC/SDADC3P: J5.2; also elsewhere on the board
GND: C1.1, C2.2, C3.1, C4.1, C5.2, C6.2, C7.2, C8.2, C9.2, C10.2, C11.2, C14.2, C15.2, C16.2, C17.2, J1.5, J1.6, J9.1, J9.2, R2.2, SW1.1, U1.8 (VSSA), U1.23 (VSSSD), U1.47 (VSS), U2.1 (GND); also elsewhere on the board
unnamed: C2.1, D1.1 (K), U2.3 (VI)
unnamed: C4.2, R1.1, Y1.2

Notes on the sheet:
Voltage regulator
VDD-VSS
VDDA-VSSA
VREFSD+
NRST
HSE Crystal
VDDSD
BOOT0
Misc

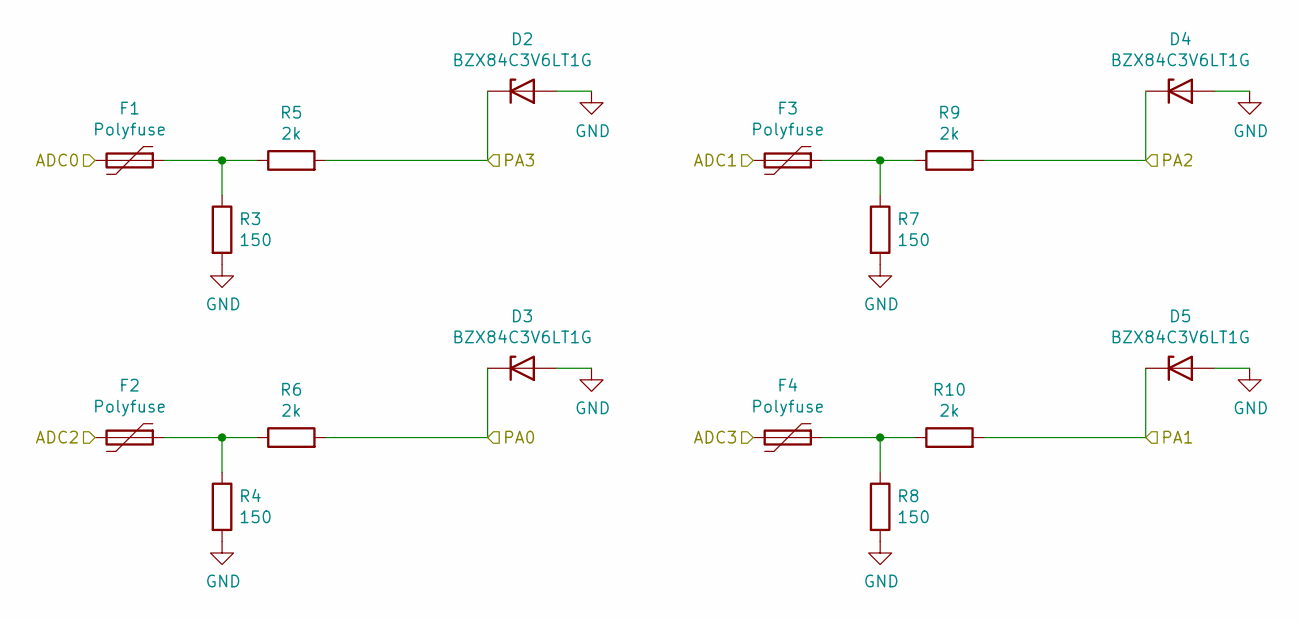
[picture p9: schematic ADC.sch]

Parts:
D2, D3, D4, D5: BZX84C3V6LT1G; D_SOT-23_ANK
F1, F2, F3, F4: Polyfuse; Fuse_0603_1608Metric
R3, R4, R7, R8: 150; R_1206_3216Metric
R5, R6, R9, R10: 2k; R_1206_3216Metric

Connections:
/ADC/ADC0: F1.2; also elsewhere on the board
/ADC/ADC1: F3.2; also elsewhere on the board
/ADC/ADC2: F2.2; also elsewhere on the board
/ADC/ADC3: F4.2; also elsewhere on the board
/PA0: D3.1 (K), R6.2; also elsewhere on the board
/PA1: D5.1 (K), R10.2; also elsewhere on the board
/PA2: D4.1 (K), R9.2; also elsewhere on the board
/PA3: D2.1 (K), R5.2; also elsewhere on the board
GND: D2.2 (A), D3.2 (A), D4.2 (A), D5.2 (A), R3.2, R4.2, R7.2, R8.2; also elsewhere on the board
unnamed: F1.1, R3.1, R5.1
unnamed: F2.1, R4.1, R6.1
unnamed: F3.1, R7.1, R9.1
unnamed: F4.1, R8.1, R10.1

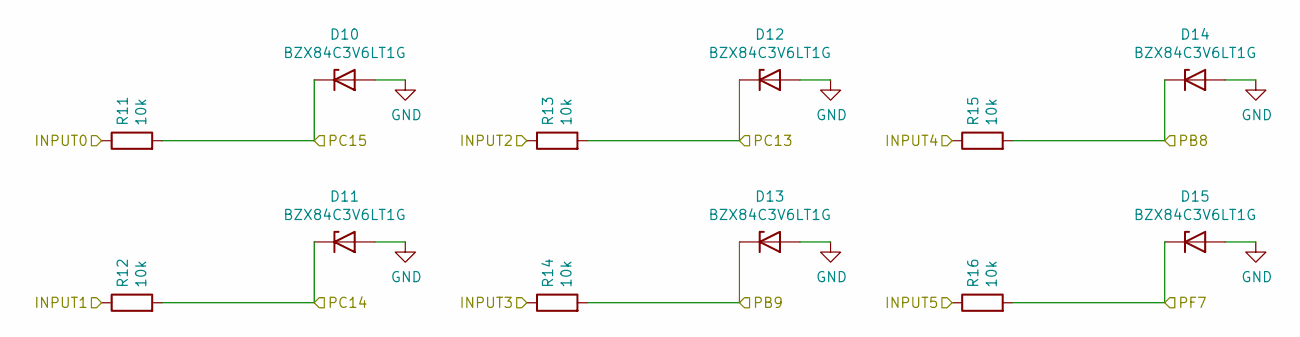
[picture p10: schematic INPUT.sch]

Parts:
D10, D11, D12, D13, D14, D15: BZX84C3V6LT1G; D_SOT-23_ANK
R11, R12, R13, R14, R15, R16: 10k; R_1206_3216Metric

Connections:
/INPUT/INPUT0: R11.1; also elsewhere on the board
/INPUT/INPUT1: R12.1; also elsewhere on the board
/INPUT/INPUT2: R13.1; also elsewhere on the board
/INPUT/INPUT3: R14.1; also elsewhere on the board
/INPUT/INPUT4: R15.1; also elsewhere on the board
/INPUT/INPUT5: R16.1; also elsewhere on the board
/PB8: D14.1 (K), R15.2; also elsewhere on the board
/PB9: D13.1 (K), R14.2; also elsewhere on the board
/PC13: D12.1 (K), R13.2; also elsewhere on the board
/PC14: D11.1 (K), R12.2; also elsewhere on the board
/PC15: D10.1 (K), R11.2; also elsewhere on the board
/PF7: D15.1 (K), R16.2; also elsewhere on the board
GND: D10.2 (A), D11.2 (A), D12.2 (A), D13.2 (A), D14.2 (A), D15.2 (A); also elsewhere on the board

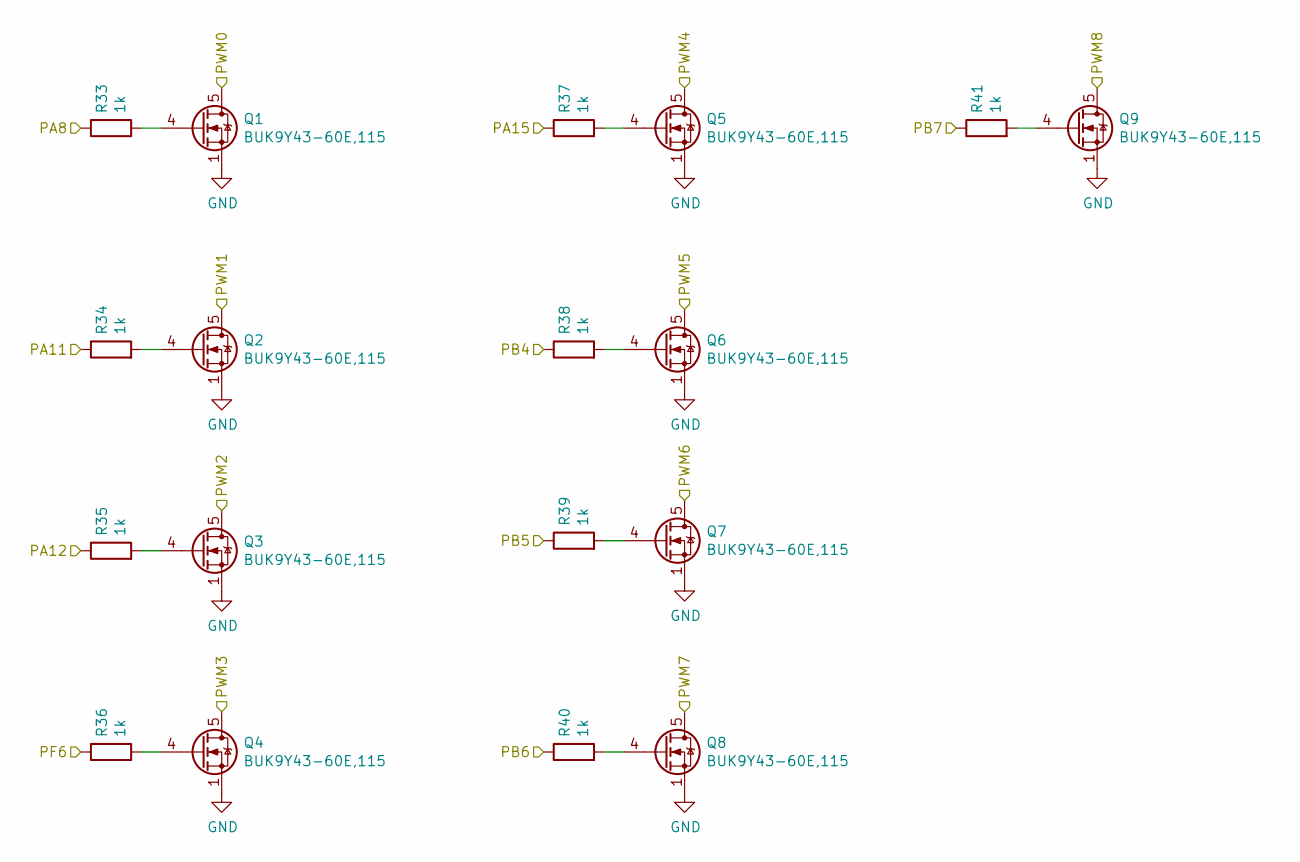
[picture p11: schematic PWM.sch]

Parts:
Q1, Q2, Q3, Q4, Q5, Q6, Q7, Q8, Q9: BUK9Y43-60E,115; LFPAK56
R33, R34, R35, R36, R37, R38, R39, R40, R41: 1k; R_1206_3216Metric

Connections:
/PA8: R33.1; also elsewhere on the board
/PA11: R34.1; also elsewhere on the board
/PA12: R35.1; also elsewhere on the board
/PA15: R37.1; also elsewhere on the board
/PB4: R38.1; also elsewhere on the board
/PB5: R39.1; also elsewhere on the board
/PB6: R40.1; also elsewhere on the board
/PB7: R41.1; also elsewhere on the board
/PF6: R36.1; also elsewhere on the board
/PWM/PWM0: Q1.5 (D); also elsewhere on the board
/PWM/PWM1: Q2.5 (D); also elsewhere on the board
/PWM/PWM2: Q3.5 (D); also elsewhere on the board
/PWM/PWM3: Q4.5 (D); also elsewhere on the board
/PWM/PWM4: Q5.5 (D); also elsewhere on the board
/PWM/PWM5: Q6.5 (D); also elsewhere on the board
/PWM/PWM6: Q7.5 (D); also elsewhere on the board
/PWM/PWM7: Q8.5 (D); also elsewhere on the board
/PWM/PWM8: Q9.5 (D); also elsewhere on the board
GND: Q1.1 (S), Q1.2 (S), Q1.3 (S), Q2.1 (S), Q2.2 (S), Q2.3 (S), Q3.1 (S), Q3.2 (S), Q3.3 (S), Q4.1 (S), Q4.2 (S), Q4.3 (S), Q5.1 (S), Q5.2 (S), Q5.3 (S), Q6.1 (S), Q6.2 (S), Q6.3 (S), Q7.1 (S), Q7.2 (S), Q7.3 (S), Q8.1 (S), Q8.2 (S), Q8.3 (S), Q9.1 (S), Q9.2 (S), Q9.3 (S); also elsewhere on the board
unnamed: Q1.4 (G), R33.2
unnamed: Q2.4 (G), R34.2
unnamed: Q3.4 (G), R35.2
unnamed: Q4.4 (G), R36.2
unnamed: Q5.4 (G), R37.2
unnamed: Q6.4 (G), R38.2
unnamed: Q7.4 (G), R39.2
unnamed: Q8.4 (G), R40.2
unnamed: Q9.4 (G), R41.2

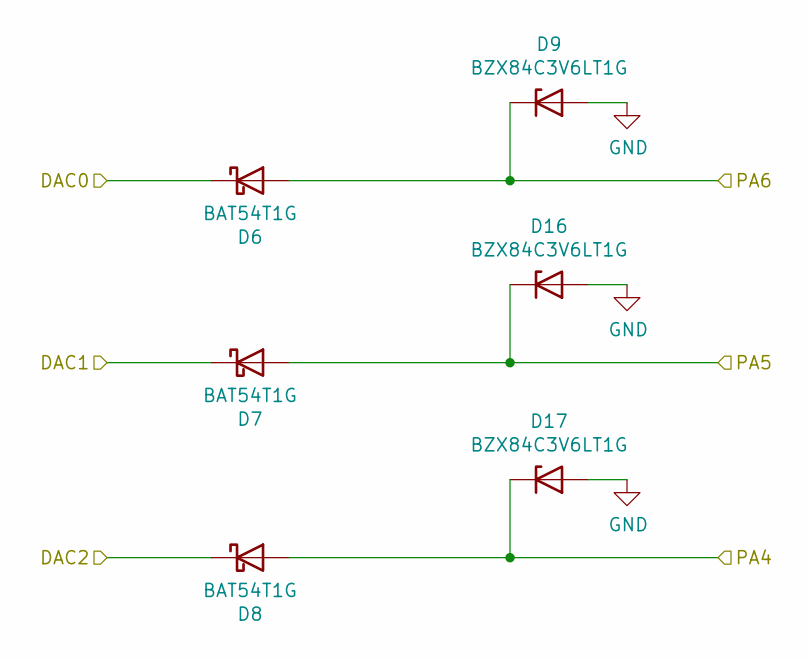
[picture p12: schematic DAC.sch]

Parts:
D6, D7, D8: BAT54T1G; D_SOD-123
D9, D16, D17: BZX84C3V6LT1G; D_SOT-23_ANK

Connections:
/DAC/DAC0: D6.1 (K); also elsewhere on the board
/DAC/DAC1: D7.1 (K); also elsewhere on the board
/DAC/DAC2: D8.1 (K); also elsewhere on the board
/PA4: D8.2 (A), D17.1 (K); also elsewhere on the board
/PA5: D7.2 (A), D16.1 (K); also elsewhere on the board
/PA6: D6.2 (A), D9.1 (K); also elsewhere on the board
GND: D9.2 (A), D16.2 (A), D17.2 (A); also elsewhere on the board

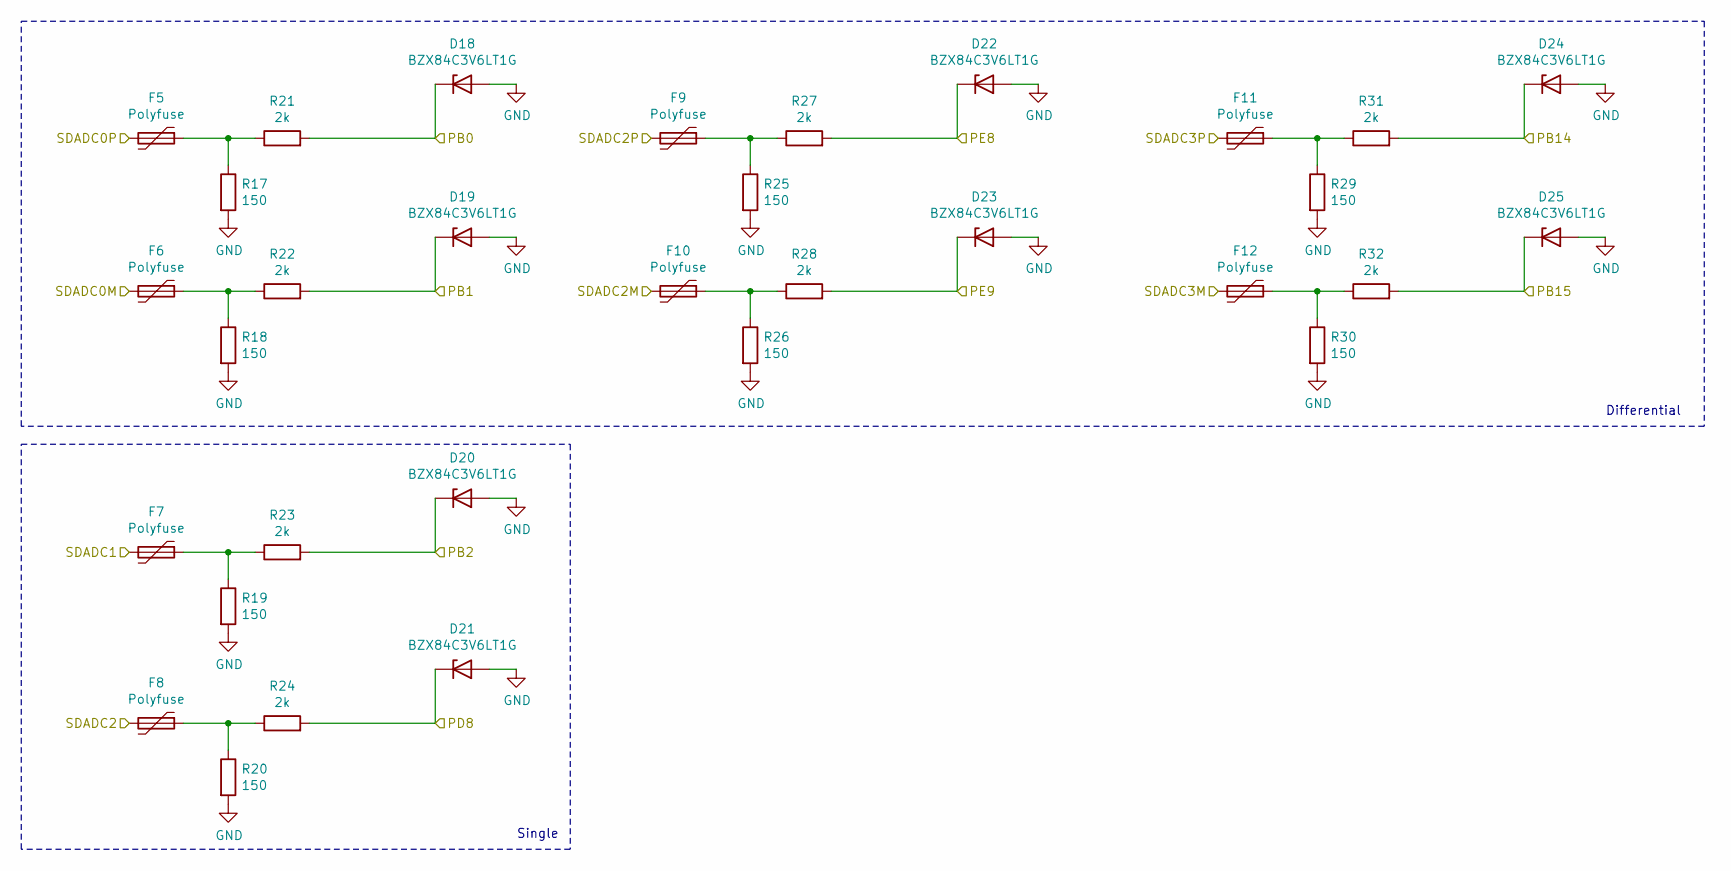
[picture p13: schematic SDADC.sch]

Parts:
D18, D19, D20, D21, D22, D23, D24, D25: BZX84C3V6LT1G; D_SOT-23_ANK
F5, F6, F7, F8, F9, F10, F11, F12: Polyfuse; Fuse_0603_1608Metric
R17, R18, R19, R20, R25, R26, R29, R30: 150; R_1206_3216Metric
R21, R22, R23, R24, R27, R28, R31, R32: 2k; R_1206_3216Metric

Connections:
/PB0: D18.1 (K), R21.2; also elsewhere on the board
/PB1: D19.1 (K), R22.2; also elsewhere on the board
/PB2: D20.1 (K), R23.2; also elsewhere on the board
/PB14: D24.1 (K), R31.2; also elsewhere on the board
/PB15: D25.1 (K), R32.2; also elsewhere on the board
/PD8: D21.1 (K), R24.2; also elsewhere on the board
/PE8: D22.1 (K), R27.2; also elsewhere on the board
/PE9: D23.1 (K), R28.2; also elsewhere on the board
/SDADC/SDADC0M: F6.2; also elsewhere on the board
/SDADC/SDADC0P: F5.2; also elsewhere on the board
/SDADC/SDADC1: F7.2; also elsewhere on the board
/SDADC/SDADC2: F8.2; also elsewhere on the board
/SDADC/SDADC2M: F10.2; also elsewhere on the board
/SDADC/SDADC2P: F9.2; also elsewhere on the board
/SDADC/SDADC3M: F12.2; also elsewhere on the board
/SDADC/SDADC3P: F11.2; also elsewhere on the board
GND: D18.2 (A), D19.2 (A), D20.2 (A), D21.2 (A), D22.2 (A), D23.2 (A), D24.2 (A), D25.2 (A), R17.2, R18.2, R19.2, R20.2, R25.2, R26.2, R29.2, R30.2; also elsewhere on the board
unnamed: F5.1, R17.1, R21.1
unnamed: F6.1, R18.1, R22.1
unnamed: F7.1, R19.1, R23.1
unnamed: F8.1, R20.1, R24.1
unnamed: F9.1, R25.1, R27.1
unnamed: F10.1, R26.1, R28.1
unnamed: F11.1, R29.1, R31.1
unnamed: F12.1, R30.1, R32.1

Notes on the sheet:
Differential
Single

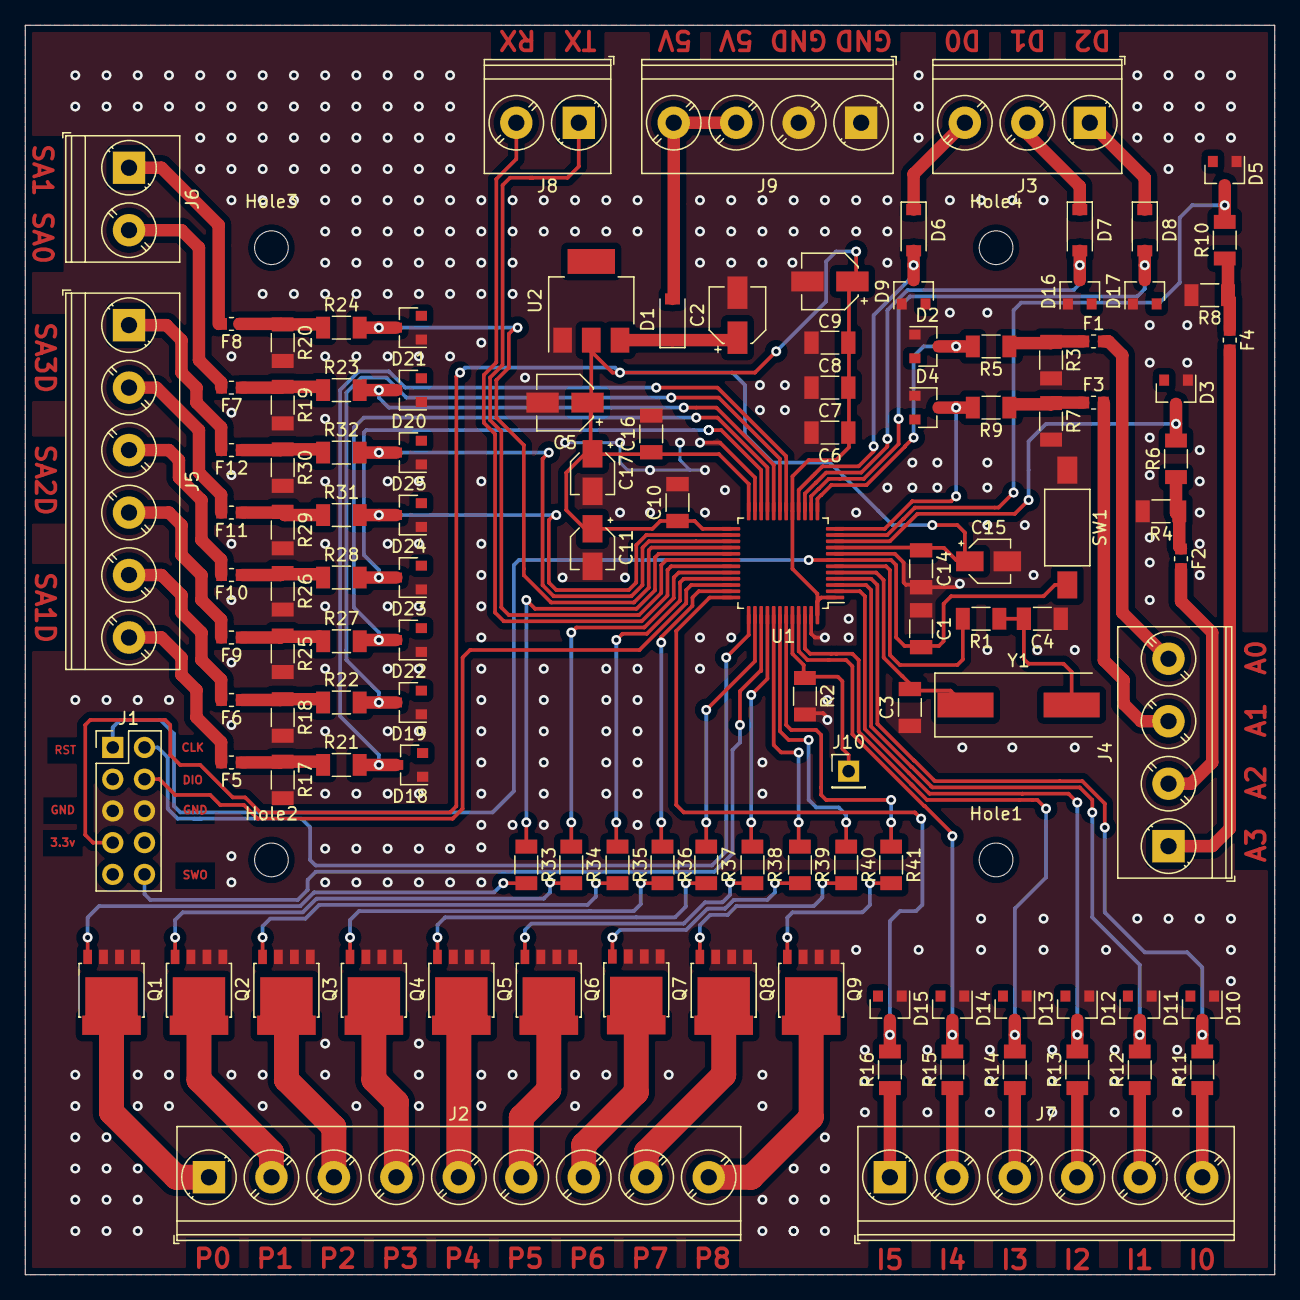
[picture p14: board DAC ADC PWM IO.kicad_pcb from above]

Board: 2 copper layers, 100.0 x 100.0 mm, 120 parts (0 on the bottom side), 95 nets.

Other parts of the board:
Hole1, Hole2, Hole3, Hole4: MountingHole_2.7mm

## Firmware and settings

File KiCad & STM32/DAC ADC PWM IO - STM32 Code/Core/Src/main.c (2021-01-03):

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
/* Includes ------------------------------------------------------------------*/
#include "main.h"

/* USER CODE BEGIN Includes */
#include "FlashMemory_F3/ReadWrite.h"
/* USER CODE END Includes */

ADC_HandleTypeDef hadc1;
DMA_HandleTypeDef hdma_adc1;

DAC_HandleTypeDef hdac1;
DAC_HandleTypeDef hdac2;

SDADC_HandleTypeDef hsdadc1;
SDADC_HandleTypeDef hsdadc3;

TIM_HandleTypeDef htim2;
TIM_HandleTypeDef htim3;
TIM_HandleTypeDef htim4;
TIM_HandleTypeDef htim5;
TIM_HandleTypeDef htim6;
TIM_HandleTypeDef htim19;

UART_HandleTypeDef huart1;
DMA_HandleTypeDef hdma_usart1_rx;

/* USER CODE BEGIN PV */
uint8_t RX_DATA[1 + 9 * 2 + 3 * 2] = { 0 }; // Choice + PWM + DAC
uint8_t TX_DATA[4 * 2 + 2 * 2 + 3 * 2 + 6] = { 0 }; // ADC + SDADC + DSDADC + DI
uint16_t PWM_PERIOD[9] = { 0 };
uint16_t DAC_OUTPUT[3] = { 0 };
uint16_t ADC_VALUES[4] = { 0 };
uint16_t SD_ADC[6] = {0}; // For both Differential and single
uint16_t DI_VALUES[6] = { 0 };
uint16_t TIM_PRESCALES[4] = { 0 }; // TIM2, TIM3, TIM4, TIM5
uint32_t CHANNEL = 4; // SD-ADC channels
/* USER CODE END PV */

void SystemClock_Config(void);
static void MX_GPIO_Init(void);
static void MX_DMA_Init(void);
static void MX_ADC1_Init(void);
static void MX_DAC1_Init(void);
static void MX_DAC2_Init(void);
static void MX_SDADC1_Init(void);
static void MX_SDADC3_Init(void);
static void MX_TIM2_Init(void);
static void MX_TIM3_Init(void);
static void MX_TIM4_Init(void);
static void MX_TIM5_Init(void);
static void MX_USART1_UART_Init(void);
static void MX_TIM19_Init(void);
static void MX_TIM6_Init(void);
/* USER CODE BEGIN PFP */
void fill_uint16_array(uint8_t array8[], uint16_t array16[], uint8_t elements_that_has_been_written, uint8_t size);
void fill_TX_DATA_16(uint8_t array8[], uint16_t array16[], uint8_t elements_that_has_been_written, uint8_t size);
void fill_TX_DATA_8(uint8_t array8[], uint16_t array16[], uint8_t elements_that_has_been_written, uint8_t size);
void read_PWM_TIM_prescalers_from_memory();
void write_PWM_TIM_prescalers_to_memory();
void read_PWM_DAC_periods_send_measurement_back();
void is_ready();
void is_not_ready();
/* USER CODE END PFP */

/**
  * @brief  The application entry point.
  * @retval int
  */
int main(void)
{
  /* MCU Configuration--------------------------------------------------------*/

  /* Reset of all peripherals, Initializes the Flash interface and the Systick. */
  HAL_Init();

  /* Configure the system clock */
  SystemClock_Config();

  /* Initialize all configured peripherals */
  MX_GPIO_Init();
  MX_DMA_Init();
  MX_ADC1_Init();
  MX_DAC1_Init();
  MX_DAC2_Init();
  MX_SDADC1_Init();
  MX_SDADC3_Init();
  MX_TIM2_Init();
  MX_TIM3_Init();
  MX_TIM4_Init();
  MX_TIM5_Init();
  MX_USART1_UART_Init();
  MX_TIM19_Init();
  MX_TIM6_Init();
  /* USER CODE BEGIN 2 */

	// DMA UART
	uint8_t RX_DATA_element_size = sizeof(RX_DATA);
	HAL_UART_Receive_DMA(&huart1, RX_DATA, RX_DATA_element_size);

	// TIM Trig
	HAL_TIM_Base_Start(&htim6); // For DAC
	HAL_TIM_Base_Start(&htim19); // For ADC

	// DMA ADC
	uint8_t ADC_element_size = sizeof(ADC_VALUES) / sizeof(ADC_VALUES[0]);
	HAL_ADC_Start_DMA(&hadc1, (uint32_t*) ADC_VALUES, ADC_element_size);

	// IT SD ADC
	HAL_SDADC_Start_IT(&hsdadc1);
	HAL_SDADC_Start_IT(&hsdadc3);

	// DAC
	HAL_DAC_Start(&hdac1, DAC1_CHANNEL_1);
	HAL_DAC_Start(&hdac1, DAC1_CHANNEL_2);
	HAL_DAC_Start(&hdac2, DAC1_CHANNEL_1);

	// PWM
	HAL_TIM_PWM_Start(&htim2, TIM_CHANNEL_1);
	HAL_TIM_PWM_Start(&htim3, TIM_CHANNEL_1);
	HAL_TIM_PWM_Start(&htim3, TIM_CHANNEL_2);
	HAL_TIM_PWM_Start(&htim4, TIM_CHANNEL_1);
	HAL_TIM_PWM_Start(&htim4, TIM_CHANNEL_2);
	HAL_TIM_PWM_Start(&htim4, TIM_CHANNEL_4);
	HAL_TIM_PWM_Start(&htim5, TIM_CHANNEL_1);
	HAL_TIM_PWM_Start(&htim5, TIM_CHANNEL_2);
	HAL_TIM_PWM_Start(&htim5, TIM_CHANNEL_3);

	// Set the PWM timers
	FlashSetAddrs(0x0803F800);
	read_PWM_TIM_prescalers_from_memory();

  /* USER CODE END 2 */

  /* Infinite loop */
  /* USER CODE BEGIN WHILE */
	while (1) {
    /* USER CODE END WHILE */

    /* USER CODE BEGIN 3 */
		// TIM 2
		htim2.Instance->CCR1 = PWM_PERIOD[4]; // P4
		// TIM 3
		htim3.Instance->CCR1 = PWM_PERIOD[5]; // P5
		htim3.Instance->CCR2 = PWM_PERIOD[6]; // P6
		// TIM 4
		htim4.Instance->CCR1 = PWM_PERIOD[7]; // P7
		htim4.Instance->CCR2 = PWM_PERIOD[8]; // P8
		htim4.Instance->CCR4 = PWM_PERIOD[3]; // P3
		// TIM 5
		htim5.Instance->CCR1 = PWM_PERIOD[0]; // P0
		htim5.Instance->CCR2 = PWM_PERIOD[1]; // P1
		htim5.Instance->CCR3 = PWM_PERIOD[2]; // P2
		// DAC 1
		HAL_DAC_SetValue(&hdac1, DAC1_CHANNEL_1, DAC_ALIGN_12B_R, DAC_OUTPUT[2]); // D2
		HAL_DAC_SetValue(&hdac1, DAC1_CHANNEL_2, DAC_ALIGN_12B_R, DAC_OUTPUT[1]); // D1
		// DAC 2
		HAL_DAC_SetValue(&hdac2, DAC1_CHANNEL_1, DAC_ALIGN_12B_R, DAC_OUTPUT[0]); // D0
		// DI
		DI_VALUES[0] = HAL_GPIO_ReadPin(INPUT_0_GPIO_Port, INPUT_0_Pin); // I0
		DI_VALUES[1] = HAL_GPIO_ReadPin(INPUT_1_GPIO_Port, INPUT_1_Pin); // I1
		DI_VALUES[2] = HAL_GPIO_ReadPin(INPUT_2_GPIO_Port, INPUT_2_Pin); // I2
		DI_VALUES[3] = HAL_GPIO_ReadPin(INPUT_3_GPIO_Port, INPUT_3_Pin); // I3
		DI_VALUES[4] = HAL_GPIO_ReadPin(INPUT_4_GPIO_Port, INPUT_4_Pin); // I4
		DI_VALUES[5] = HAL_GPIO_ReadPin(INPUT_5_GPIO_Port, INPUT_5_Pin); // I5
	}
  /* USER CODE END 3 */
}

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
/* USER CODE BEGIN 4 */
// When we got a complete RX message - This function runs
void HAL_UART_RxCpltCallback(UART_HandleTypeDef *huart) {
	/* Prevent unused argument(s) compilation warning */
	UNUSED(huart);

	/* NOTE : This function should not be modified, when the callback is needed,
	 the HAL_UART_RxCpltCallback can be implemented in the user file.
	 */

	uint8_t choice = RX_DATA[0];
	switch (choice) {
	case 48: // Ask if is ready
		is_ready();
		break;
	case 49: // Set PWM and DAC periods and also send measurements back
		read_PWM_DAC_periods_send_measurement_back();
		break;
	case 50: // Set Timers prescalers to memory and send status OK back
		write_PWM_TIM_prescalers_to_memory();
		break;
	default: // Answer back that this uC is not ready
		is_not_ready();
		break;
	}
}

// When we got a measurement
void HAL_SDADC_InjectedConvCpltCallback(SDADC_HandleTypeDef *hsdadc){
	// CHANNEL will be 4, 6, 8 but randomly
	// SD_ADC for SDADC1 = [SDADC1_IN4, 0, SDADC1_IN6, SDADC3_IN6, SDADC1_IN8, SDADC3_IN8];
	if(hsdadc->Instance == SDADC1){
		SD_ADC[CHANNEL - 4] = HAL_SDADC_InjectedGetValue(hsdadc, &CHANNEL);
	}else if(hsdadc->Instance == SDADC3){
		SD_ADC[CHANNEL - 4 + 1] = HAL_SDADC_InjectedGetValue(hsdadc, &CHANNEL);
	}
}

// Send back that it's true at first element
void is_ready(){
	uint8_t TX_DATA_element_size = sizeof(TX_DATA) / sizeof(TX_DATA[0]);
	TX_DATA[0] = 1;
	HAL_UART_Transmit(&huart1, TX_DATA, TX_DATA_element_size, 10);
}

// Send back that it's false at first element
void is_not_ready(){
	uint8_t TX_DATA_element_size = sizeof(TX_DATA) / sizeof(TX_DATA[0]);
	TX_DATA[0] = 0;
	HAL_UART_Transmit(&huart1, TX_DATA, TX_DATA_element_size, 10);
}

void read_PWM_DAC_periods_send_measurement_back() {
	// Get the PWM and DAC values
	uint8_t PWM_element_size = sizeof(PWM_PERIOD) / sizeof(PWM_PERIOD[0]);
	uint8_t DAC_element_size = sizeof(DAC_OUTPUT) / sizeof(DAC_OUTPUT[0]);
	fill_uint16_array(RX_DATA, PWM_PERIOD, 1, PWM_element_size); // 1 because the first element is the choice above
	fill_uint16_array(RX_DATA, DAC_OUTPUT, PWM_element_size * 2 + 1, DAC_element_size);

	// Copy over
	uint16_t SD_ADC_VALUES[2] = {SD_ADC[0], SD_ADC[3]};
	uint16_t D_SD_ADC_VALUES[3] = {SD_ADC[2], SD_ADC[4], SD_ADC[5]}; // SD_ADC[1] = empty

	// Send the ADC, SDADC, DSDADC and DI values
	uint8_t ADC_element_size = sizeof(ADC_VALUES) / sizeof(ADC_VALUES[0]);
	uint8_t SD_ADC_element_size = sizeof(SD_ADC_VALUES) / sizeof(SD_ADC_VALUES[0]);
	uint8_t D_SD_ADC_element_size = sizeof(D_SD_ADC_VALUES) / sizeof(D_SD_ADC_VALUES[0]);
	uint8_t DI_element_size = sizeof(DI_VALUES) / sizeof(DI_VALUES[0]);
	uint8_t TX_DATA_element_size = sizeof(TX_DATA) / sizeof(TX_DATA[0]);
	fill_TX_DATA_16(TX_DATA, ADC_VALUES, 0, ADC_element_size);
	fill_TX_DATA_16(TX_DATA, SD_ADC_VALUES, ADC_element_size * 2, SD_ADC_element_size);
	fill_TX_DATA_16(TX_DATA, D_SD_ADC_VALUES, (ADC_element_size + SD_ADC_element_size) * 2, D_SD_ADC_element_size);
	fill_TX_DATA_8(TX_DATA, DI_VALUES, (ADC_element_size + SD_ADC_element_size + D_SD_ADC_element_size) * 2, DI_element_size);
	HAL_UART_Transmit(&huart1, TX_DATA, TX_DATA_element_size, 10);
}

void fill_uint16_array(uint8_t array8[], uint16_t array16[],
		uint8_t elements_that_has_been_written, uint8_t size) {
	for (uint8_t i = 0; i < size; i++) {
		array16[i] = (array8[i + i + elements_that_has_been_written] << 8) | (array8[i + i + 1 + elements_that_has_been_written] & 0xFF);
	}
}

void fill_TX_DATA_16(uint8_t array8[], uint16_t array16[],
		uint8_t elements_that_has_been_written, uint8_t size) {
	for (uint8_t i = 0; i < size; i++) {
		array8[i + i + elements_that_has_been_written] = array16[i] >> 8;
		array8[i + i + 1 + elements_that_has_been_written] = array16[i];
	}
}

void fill_TX_DATA_8(uint8_t array8[], uint16_t array16[],
		uint8_t elements_that_has_been_written, uint8_t size) {
	for (uint8_t i = 0; i < size; i++) {
		array8[i + elements_that_has_been_written] = array16[i];
	}
}

void read_PWM_TIM_prescalers_from_memory() {
	uint32_t Nsize = sizeof(TIM_PRESCALES) / sizeof(TIM_PRESCALES[0]);
	FlashReadN(0, TIM_PRESCALES, Nsize, DATA_TYPE_U16);
	htim2.Instance->PSC = TIM_PRESCALES[0];
	htim3.Instance->PSC = TIM_PRESCALES[1];
	htim4.Instance->PSC = TIM_PRESCALES[2];
	htim5.Instance->PSC = TIM_PRESCALES[3];
}

void write_PWM_TIM_prescalers_to_memory() {
	uint32_t Nsize = sizeof(TIM_PRESCALES) / sizeof(TIM_PRESCALES[0]);
	uint16_t wrBuf[Nsize];
	fill_uint16_array(RX_DATA, wrBuf, 1, Nsize); // 1 because choice is first element
	FlashWriteN(0, wrBuf, Nsize, DATA_TYPE_U16);
	read_PWM_TIM_prescalers_from_memory();
	is_ready();
}

/* USER CODE END 4 */
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


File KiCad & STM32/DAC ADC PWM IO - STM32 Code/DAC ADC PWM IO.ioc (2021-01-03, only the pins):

Mcu.UserName=STM32F373CCTx
PA0.Signal=ADC1_IN0
PA1.Signal=ADC1_IN1
PA10.Signal=USART1_RX
PA11.Signal=S_TIM5_CH2
PA12.Signal=S_TIM5_CH3
PA13.Signal=SYS_JTMS-SWDIO
PA14.Signal=SYS_JTCK-SWCLK
PA15.Signal=S_TIM2_CH1_ETR
PA2.Signal=ADC1_IN2
PA3.Signal=ADC1_IN3
PA4.Signal=COMP_DAC11_group
PA5.Signal=COMP_DAC12_group
PA6.Signal=COMP_DAC21_group
PA8.Signal=S_TIM5_CH1_ETR
PA9.Signal=USART1_TX
PB0.Signal=SDADC1_AIN6P
PB1.Signal=SDADC1_AIN6M
PB14.Signal=SDADC3_AIN8P
PB15.Signal=SDADC3_AIN8M
PB2.Signal=SDADC1_AIN4P
PB3.Signal=SYS_JTDO-TRACESWO
PB4.Signal=S_TIM3_CH1
PB5.Signal=S_TIM3_CH2
PB6.Signal=S_TIM4_CH1
PB7.Signal=S_TIM4_CH2
PB8.GPIO_Label=INPUT 4
PB8.Signal=GPIO_Input
PB9.GPIO_Label=INPUT 3
PB9.Signal=GPIO_Input
PC13.GPIO_Label=INPUT 2
PC13.Signal=GPIO_Input
PC14-OSC32_IN.GPIO_Label=INPUT 1
PC14-OSC32_IN.Signal=GPIO_Input
PC15-OSC32_OUT.GPIO_Label=INPUT 0
PC15-OSC32_OUT.Signal=GPIO_Input
PD8.Signal=SDADC3_AIN6P
PE8.Signal=SDADC1_AIN8P
PE9.Signal=SDADC1_AIN8M
PF0-OSC_IN.Signal=RCC_OSC_IN
PF1-OSC_OUT.Signal=RCC_OSC_OUT
PF6.Signal=S_TIM4_CH4
PF7.GPIO_Label=INPUT 5
PF7.Signal=GPIO_Input

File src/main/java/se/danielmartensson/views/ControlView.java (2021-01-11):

package se.danielmartensson.views;

import java.util.ArrayList;
import java.util.List;
import java.util.concurrent.atomic.AtomicBoolean;

import javax.annotation.PostConstruct;

import org.springframework.beans.factory.annotation.Autowired;
import org.springframework.context.annotation.PropertySource;

import com.github.appreciated.apexcharts.ApexCharts;
import com.vaadin.flow.component.UI;
import com.vaadin.flow.component.applayout.AppLayout;
import com.vaadin.flow.component.button.Button;
import com.vaadin.flow.component.checkbox.Checkbox;
import com.vaadin.flow.component.dependency.CssImport;
import com.vaadin.flow.component.html.Label;
import com.vaadin.flow.component.notification.Notification;
import com.vaadin.flow.component.orderedlayout.FlexComponent.Alignment;
import com.vaadin.flow.component.select.Select;
import com.vaadin.flow.component.textfield.IntegerField;
import com.vaadin.flow.component.textfield.TextField;
import com.vaadin.flow.component.orderedlayout.HorizontalLayout;
import com.vaadin.flow.component.orderedlayout.VerticalLayout;
import com.vaadin.flow.component.page.Push;
import com.vaadin.flow.router.Route;

import lombok.Getter;
import se.danielmartensson.entities.Data;
import se.danielmartensson.entities.Job;
import se.danielmartensson.hardware.Serial;
import se.danielmartensson.service.AlarmService;
import se.danielmartensson.service.DataService;
import se.danielmartensson.service.JobService;
import se.danielmartensson.service.MailService;
import se.danielmartensson.threads.ControlThread;
import se.danielmartensson.threads.SamplingThread;
import se.danielmartensson.tools.Graf;
import se.danielmartensson.tools.PaperSlider;
import se.danielmartensson.tools.Top;

@Route("control")
@CssImport("./styles/shared-styles.css")
@CssImport(value = "./styles/vaadin-text-field-styles.css", themeFor = "vaadin-text-field")
@Push
/**
 * This class handles the control view.
 * 
 * @author dell
 *
 */
@Getter
@PropertySource("classpath:application.properties")
public class ControlView extends AppLayout {

	/**
	 * 
	 */
	private static final long serialVersionUID = 1L;

	public static final String START_LOGGING = "Start logging";
	public static final String STOP_LOGGING = "Stop logging";
	public static final Integer MAX_SLIDER_VALE = 4095;

	// Button that the thread need to have access to
	private Button loggingActivate;

	// Services
	private JobService jobService;
	private MailService mailService;
	private DataService dataService;
	private AlarmService alarmService;

	// Static for the UI - Also initial values
	public static Job selectedJob;
	public static int selectedSamplingTime = 10;
	public static int selectedShowSamples = 10;
	public static boolean selectedShowPlot;
	public static int sliderSelectedP0 = 0;
	public static int sliderSelectedP1 = 0;
	public static int sliderSelectedP2 = 0;
	public static int sliderSelectedP3 = 0;
	public static int sliderSelectedP4 = 0;
	public static int sliderSelectedP5 = 0;
	public static int sliderSelectedP6 = 0;
	public static int sliderSelectedP7 = 0;
	public static int sliderSelectedP8 = 0;
	public static int sliderSelectedD0 = 0;
	public static int sliderSelectedD1 = 0;
	public static int sliderSelectedD2 = 0;
	public static int selectedBreakPulseLimit = 1;
	private static int selectBeginCountAt = 0;

	// For the thread
	public static AtomicBoolean loggingNow;
	public static ControlThread control;
	public static SamplingThread sampling;
	@Autowired
	private Serial serial;

	@PostConstruct
	public void init() {
		// Set the top and the tabs
		Top top = new Top();
		top.setTopAppLayout(this);

		// Apex chart
		ApexCharts apexChart = new Graf("Logging into MySQL").getApexChart();

		// Create PWM sliders
		List<PaperSlider> PWMSliders = createPWMSliders();

		// Create DAC sliders
		List<PaperSlider> DACSliders = createDACSliders();

		// Create pulse list drop down boxes
		List<IntegerField> counters = createPulseCounter();

		// Create check boxes for digital input signals
		Checkbox[] inputBoxes = createCheckBoxes(new String[] {Data.DIGITAL0 + " - Counter", Data.DIGITAL1 + " - Stop signal", Data.DIGITAL2, Data.DIGITAL3, Data.DIGITAL4, Data.DIGITAL5});
		
		// Create check boxes for showing the measurement series
		Checkbox[] seriesBoxes = createCheckBoxes(new String[] {Data.Analog0, Data.Analog1, Data.Analog2, Data.Analog3, Data.SigmaDelta0, Data.SigmaDelta1, Data.SigmaDeltaDifferential1, Data.SigmaDeltaDifferential2, Data.SigmaDeltaDifferential3});

		TextField maxLeftField = createHowManyPrimaryKeysLeftIntegerField();
		
		// Create control panel
		HorizontalLayout firstRow = createFirstRow(jobService, counters, maxLeftField);
		VerticalLayout secondRow = createVariableLayout(PWMSliders, DACSliders);
		HorizontalLayout thirdRow = createCheckBoxesLayout(inputBoxes);
		HorizontalLayout fourthRow = createCheckBoxesLayout(seriesBoxes);
		HorizontalLayout fifthRow = createStartButtonAndShowPlotButton(jobService);

		// Start the tread for control
		if (control == null) {
			loggingNow = new AtomicBoolean();
			control = new ControlThread(serial);
			control.start();
		}

		// Start the thread for sampling
		if (sampling == null) {
			sampling = new SamplingThread(mailService, dataService);
			sampling.start();
		}
		// Set components to sampling thread - So we can disable and enable inside the thread
		sampling.setComponentsToThread(UI.getCurrent(), firstRow, loggingActivate, apexChart, counters, inputBoxes, seriesBoxes);

		// Content
		setContent(new VerticalLayout(firstRow, secondRow, thirdRow, fourthRow, fifthRow, apexChart));
	}

	private TextField createHowManyPrimaryKeysLeftIntegerField() {
		Data data = dataService.findFirstByOrderByLocalDateTimeDesc();
		Long maxIDValue = 0L;
		if(data != null)
			maxIDValue = data.getId();
		Long wiritingLeft = Long.MAX_VALUE - maxIDValue;
		TextField maxLeftField = new TextField("Database wirting left");
		maxLeftField.setValue(Long.toString(wiritingLeft));
		maxLeftField.setEnabled(false);
		maxLeftField.setWidth("200px");
		return maxLeftField;
	}

	public ControlView(JobService jobService, MailService mailService, DataService dataService) {
		this.jobService = jobService;
		this.mailService = mailService;
		this.dataService = dataService;
	}

	private HorizontalLayout createCheckBoxesLayout(Checkbox[] checkBoxes) {
		HorizontalLayout checkBoxLayout = new HorizontalLayout();
		for (Checkbox checkbox : checkBoxes)
			checkBoxLayout.add(checkbox);
		checkBoxLayout.setAlignItems(Alignment.CENTER);
		return checkBoxLayout;
	}

	private Checkbox[] createCheckBoxes(String[] labels) {
		Checkbox[] list = new Checkbox[labels.length];
		for(int i = 0; i < labels.length; i++)
			list[i] = new Checkbox(labels[i]);
		return list;
	}
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

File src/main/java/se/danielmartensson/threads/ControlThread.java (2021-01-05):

package se.danielmartensson.threads;

import se.danielmartensson.hardware.Serial;
import se.danielmartensson.views.ControlView;

/**
 * This class read raw and write raw values to the GPIO pins and store them into
 * the static public fields
 * 
 * @author dell
 *
 */
public class ControlThread extends Thread {

	// Signal handler
	private Serial serial;

	// Inputs
	public static int[] ADC;
	public static int[] SDADC;
	public static int[] DSDADC;
	public static boolean[] DI;

	// Outputs
	public static int[] PWM;
	public static int[] DAC;

	public ControlThread(Serial serial) {
		this.serial = serial;

		// Delcare first
		ADC = new int[4]; 		// Analog to digital converter
		SDADC = new int[2]; 	// Sigma delta analog to digital converter
		DSDADC = new int[3]; 	// Differential sigma delta analog to digital converter
		DI = new boolean[6]; 	// Digital input
		PWM = new int[9]; 		// Pulse width modulation
		DAC = new int[3]; 		// Digital to analog converter
	}

	@Override
	public void run() {
		while (true) {
			// Wait loop
			while (!ControlView.loggingNow.get()) {
				try {
					Thread.sleep(1000);
				} catch (InterruptedException e) {
				}
				
				// This turn down PWM and DAC if we are not logging - Safety feature
				talkToSTM32(0,0,0,0,0,0,0,0,0,0,0,0);
			}

			// Control loop - When sampling thread are done, then this will quit too
			while (ControlView.loggingNow.get()) {
				// Send PWM and DAC to STM32 and receive measurements
				talkToSTM32(ControlView.sliderSelectedP0, 
							ControlView.sliderSelectedP1,
							ControlView.sliderSelectedP2,
							ControlView.sliderSelectedP3,
							ControlView.sliderSelectedP4,
							ControlView.sliderSelectedP5,
							ControlView.sliderSelectedP6,
							ControlView.sliderSelectedP7,
							ControlView.sliderSelectedP8,
							ControlView.sliderSelectedD0,
							ControlView.sliderSelectedD1,
							ControlView.sliderSelectedD2);
			}
		}
	}

	private void talkToSTM32(int P0, int P1, int P2, int P3, int P4, int P5, int P6, int P7, int P8, int D0, int D1, int D2) {
		// Ask if ready and then check
		serial.askIfReady();
		if(!serial.isOK())
			return;

		// Send PWM and DAC
		PWM[0] = P0;
		PWM[1] = P1;
		PWM[2] = P2;
		PWM[3] = P3;
		PWM[4] = P4;
		PWM[5] = P5;
		PWM[6] = P6;
		PWM[7] = P7;
		PWM[8] = P8;
		DAC[0] = D0;
		DAC[1] = D1;
		DAC[2] = D2;
		serial.transceive_PWM_DAC(PWM, DAC);

		// Receive ADC, SDADC, DSDADC and DI
		serial.receive_ADC_SDADC_DSDADC_DI(ADC, SDADC, DSDADC, DI);
	}
}

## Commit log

2020-08-17 New update
    [Schematic.fzz]
2020-10-05 Changes insert for MySQL
2020-10-06 Fixed Download button
2020-10-06 Implementing milliseconds in Entity
2020-10-06 Correct order of data samples now
    [MySQLView.java]
2020-10-06 Update Download Button
2020-12-22 Big update 1
    [Schematic.fzz]
2020-12-22 Uploaded STM32 board and code
2020-12-23 Solution for Raspberry Pi
2020-12-23 Update for raspberry pi camera
2020-12-23 Upload STM32 board and code
2020-12-23 Update instructions how to build the board
2020-12-23 Add Board PCB schematics and code
2020-12-23 Added STM32 files
    [ADC.sch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]
2020-12-25 Update board schematic and code with zip.
2020-12-25 Update. Found bugs. Solved issues...
    [DeviceSettingsView.java, Serial.java]
2020-12-29 Solved an issue about couted pulses
    [MySQLView.java]
2020-12-29 Fixed Sigma Delta ADC -2^15 to 0
    [ControlThread.java]
2020-12-29 16-bit ADC applied for single
2020-12-29 Changed 0-20mA to 0-22mA because I'm using 150 Ohm resistor
2020-12-30 Fixed Sigma Delta Single
    [SamplingThread.java]
2020-12-30 New calibration manual
2021-01-02 Update SMT32 Code for 9600 UART baudrate
2021-01-03 Better communication with STM32
2021-01-03 More show samples if you want
2021-01-05 Update alarmService and calibrationService
2021-01-09 Removed the calibration manual
2021-01-10 Euler simulation for first order state space equation, as filter
2021-01-10 x -> ADC
2021-01-10 Change initial Euler filtering to 1.0
2021-01-10 Correct spelling A1 to A0
    [MySQLView.java]
2021-01-11 Update - Found a bug
    [ControlView.java]
2021-02-23 Added @Transactional for deleteByJobName(String jobName)
    Got the error "No EntityManager with actual transaction available for current thread - cannot reliably process 'remove' call"

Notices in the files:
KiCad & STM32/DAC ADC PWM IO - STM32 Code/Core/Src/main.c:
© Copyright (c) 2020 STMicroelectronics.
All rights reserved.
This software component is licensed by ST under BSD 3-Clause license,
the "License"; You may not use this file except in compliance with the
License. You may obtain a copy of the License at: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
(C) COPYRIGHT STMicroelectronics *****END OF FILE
